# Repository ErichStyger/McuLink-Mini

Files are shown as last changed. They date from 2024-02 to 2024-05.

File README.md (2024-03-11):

# McuLink-Mini
Version of the NXP MCU-Link CMSIS-DAP Debug Probe with KiCad.
Many thanks to *Dario Scheuber* and his work to make this project possible!

## Background
This is the work of Dario Scheuber who created this debug probe as student at the Lucerne University of Applied Sciences and Arts at [IET](https://www.hslu.ch/en/lucerne-school-of-engineering-architecture/about-us/organization/institute/engineering-and-technology/elektrotechnik/). The project was done under the guidance of Prof. Erich Styger.

See blog article on https://mcuoneclipse.com/2024/02/06/versatile-oshw-mini-mcu-link-debug-probe-external-on-board-or-embedded/ for additional details.

## Features
This is an open hardware version of the NXP MCU-Link CMSIS-DAP debug probe, with following features and differences to the original MCU-Link:
- Open hardware design with KiCad
- Firmware compatibility with MCU-Link (LinkServer, CMSIS-DAP, ARM DAPLink)
- Dual-Layer design for lower costs
- USB-C connector instead of  Micro-USB
- USB-C connector usable to debug the LPC55S69
- 30% smaller than the original MCU-Link
- Firmware/boot push button instead of jumper
- Micro connector for UART connection instead of pin header
- Supports only 3.3V targets (no level shifters)
- Standalone version as external debug probe
- On-Board version: Solder external debug probe on your custom board (castellated pins)
- Embedded version: copy-paste into your custom board KiCad design
- BOM with assembly costs: ~$12/piece for 100 units

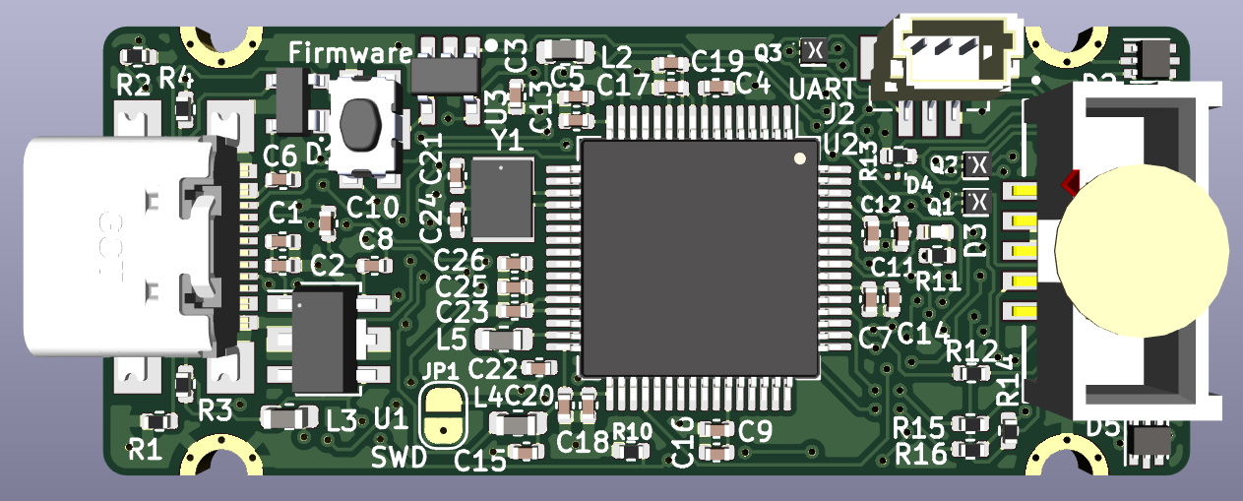
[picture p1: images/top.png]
top PCB

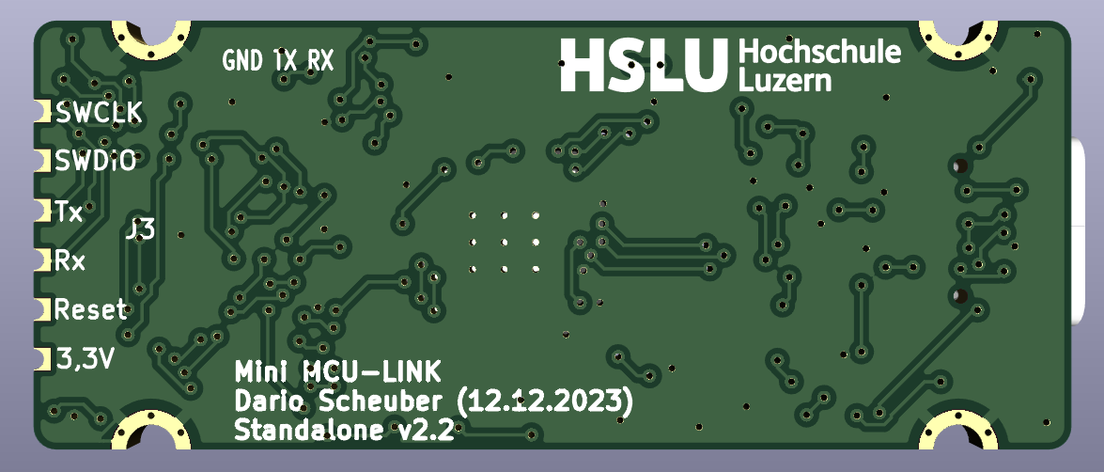
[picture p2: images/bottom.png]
bottom PCB


## Folders
- enclosure: 3D printed enclosure
- hardware: KiCad and hardware related files

## Links
- Article: https://mcuoneclipse.com/2024/02/06/versatile-oshw-mini-mcu-link-debug-probe-external-on-board-or-embedded/
- NXP MCU-Link: https://www.nxp.com/design/design-center/software/development-software/mcuxpresso-software-and-tools-/mcu-link-debug-probe:MCU-LINK
- KiCad: https://www.kicad.org/

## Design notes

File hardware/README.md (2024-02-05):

# Outline
This folder contains hardware releated files and folders:
- Gerber: production files
- KiCad: KiCad project files for the standalone, intergrated and component version of the PCB

# Errata Rev v2.1
following resistors need to be removed
- R7, R6, R9 (100 Ohm resistor for UART Rx, Tx and SWCLK)

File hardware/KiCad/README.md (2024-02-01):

Different versions of the debug probe:
- Standalone: used as standalone external debug probe
- Integrated: schematic and layout which can be pasted in your custom design
- Component: to place the standalone version with the castellated pins as component on your board

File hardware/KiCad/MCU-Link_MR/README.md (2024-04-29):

# MCU-Link

Project for the NXP MCU-Link Debug Probe with KiCAD, as a debug drone for mobile robotics platforms.

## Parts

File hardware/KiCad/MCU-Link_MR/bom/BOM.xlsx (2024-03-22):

Mouser | Vendor | Description | 1 | 10
200-SHF10501LDSM | SHF-105-01-L-D-SM | Sockel & Kabelgehäuse Shrouded Terminal Strip, 0.050" pitch | 2.88 | 2.62
771-LPC55S69JBD64K | LPC55S69JBD64K | LPC55S69JBD64 | 8.13 | 5.6
771-74LVC1T45GWQ100H | 74LVC1T45GW-Q100H | voltage converter 74LVC1T45GW-Q100/SOT363/SC-88 | 0.398 | 0.335
771-74LVC2T45DC125 | 74LVC2T45DC,125 | dual voltage converter/Bus transceiver | 0.658 | 0.546

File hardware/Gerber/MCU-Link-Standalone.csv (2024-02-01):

ID | Label | Footprint | Number | Description, Value | Reference
1 | JP1 | SolderJumper-2_P1.3mm_Open_RoundedPad1.0x1.5mm | 1 | SWD disable
2 | C22,C15,C26 | C_0402_1005Metric | 3 | 22u
3 | C21,C24 | C_0402_1005Metric | 2 | 8p
4 | J2 | JST_BM03B-SRSS-TB_LF__SN_ | 1 | BM03B-SRSS-TB
5 | U2 | LQFP-64-1EP_10x10mm_P0.5mm_EP5x5mm | 1 | LPC55S69JBD64
6 | L5 | L_0603_1608Metric | 1 | 4u7
7 | C8,C7,C25,C9,C5,C2,C18,C4,C11,C17 | C_0402_1005Metric | 10 | 100n
8 | D5,D2 | SOT-666 | 2 | PESD5V0L5UV
9 | Q2,Q3,Q1 | SOT1216 | 3 | PMDXB290UNE
10 | C10,C1 | C_0402_1005Metric | 2 | 10u
11 | R12,R6,R8,R5,R7,R9 | R_0402_1005Metric | 6 | 100
12 | C23,C19,C20 | C_0402_1005Metric | 3 | 47p
13 | SW1 | SW_C_K_KMR2 | 1 | KMR221GLFS
14 | D1 | SOT143B | 1 | PRTR5V0U2X
15 | R1,R2 | R_0402_1005Metric | 2 | 5k1
16 | U1 | SOT-89-5 | 1 | XC6227C331PR-G
17 | D3 | LED_0402_1005Metric | 1 | LED_RED
18 | C13,C6,C14,C12,C16 | C_0402_1005Metric | 5 | 10n
19 | L3,L4,L2 | L_0603_1608Metric | 3 | MI0603J601R-10
20 | R13,R14 | R_0402_1005Metric | 2 | 100k
21 | R11,R15 | R_0402_1005Metric | 2 | 2k
22 | R4 | R_0402_1005Metric | 1 | 20k
23 | U3 | SOT95P280X145-5N | 1 | STMPS2141STR
24 | D4 | Nexperia_DSN0603-2_0.6x0.3mm_P0.4mm | 1 | PMEG3005AESFYL
25 | J1 | USB_C_Receptacle_GCT_USB4110-GF-A | 1 | USB4110-GF-A_REVB
26 | R10,R3 | R_0402_1005Metric | 2 | 10k
27 | Y1 | CX3225GA16000D0PTVCC | 1 | 16.000MHz
28 | C3 | C_0402_1005Metric | 1 | 4u7
29 | R16 | R_0402_1005Metric | 1 | 10
30 | J3 | SWD_Pin_Header_Straight_2x05_Pitch1.27mm_SMD | 1 | Conn_02x05_Odd_Even

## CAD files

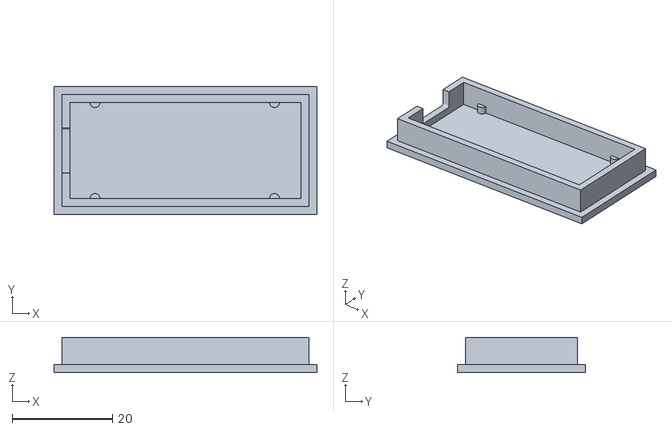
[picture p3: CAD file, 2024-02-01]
enclosure/stl/bottom.stl
52.6 x 25.6 x 7.00

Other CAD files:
enclosure/stl/top.stl
enclosure/Fusion360/bottom.f3d
enclosure/Fusion360/mini MCU-LINK assembly.f3z
enclosure/Fusion360/top.f3d

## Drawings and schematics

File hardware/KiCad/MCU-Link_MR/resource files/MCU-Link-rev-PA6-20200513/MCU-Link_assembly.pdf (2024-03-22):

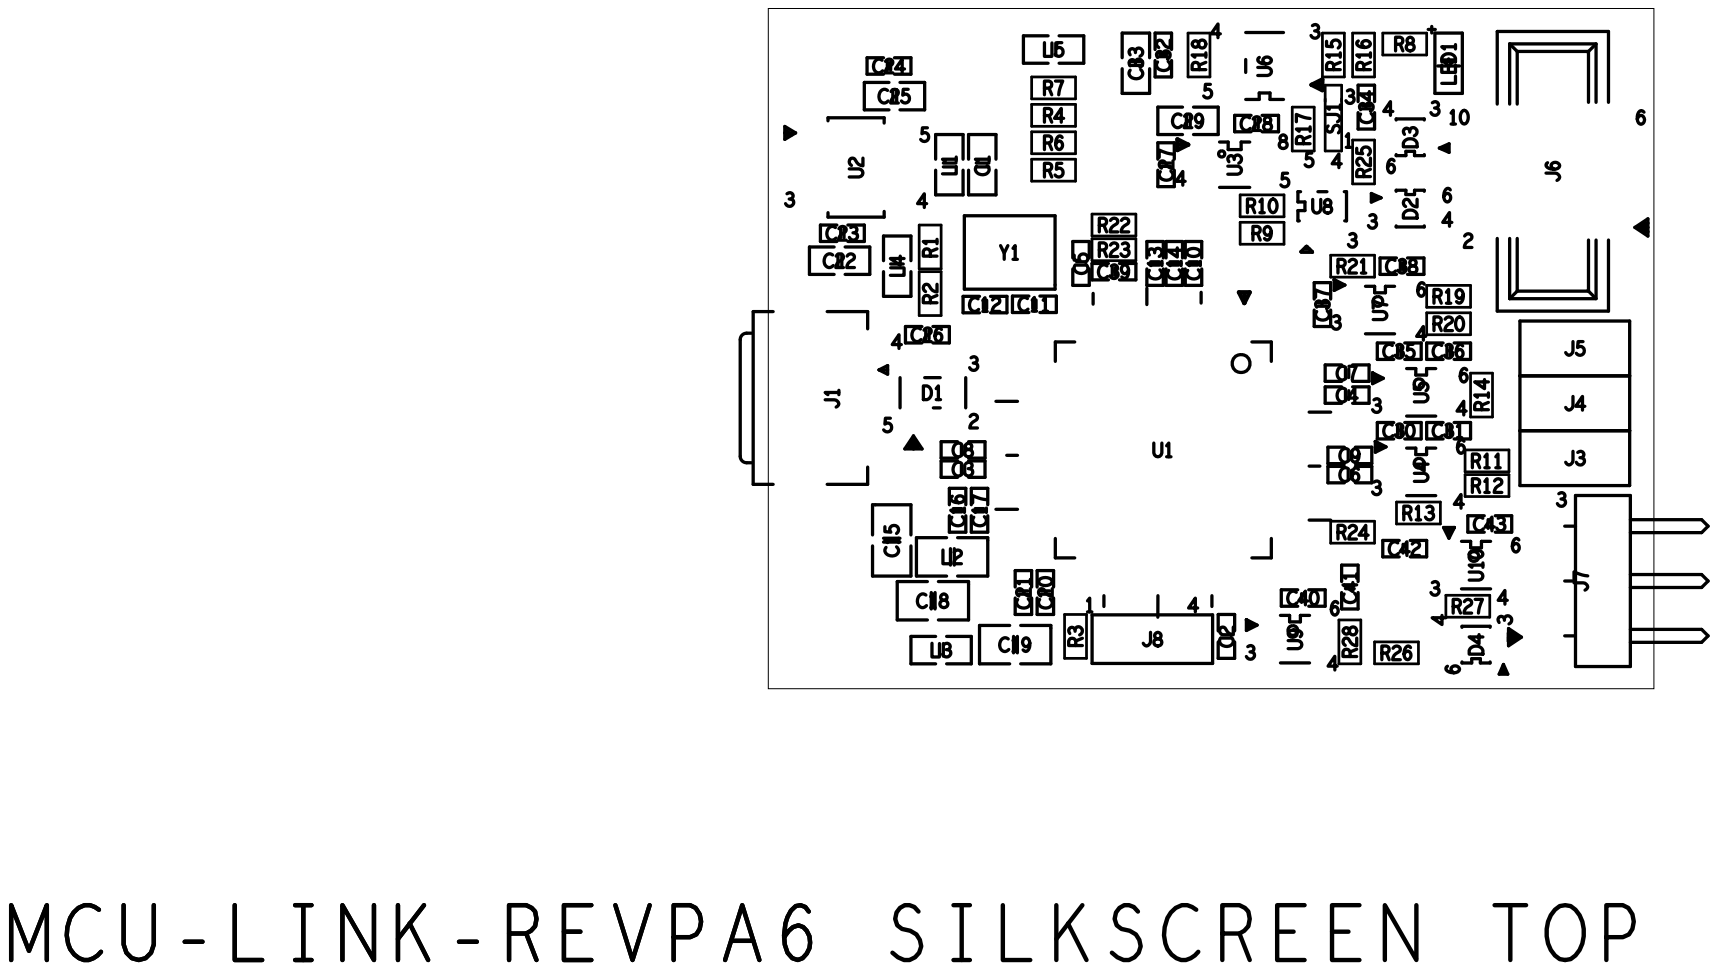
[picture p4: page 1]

MCU-LINK-REVPA6 SILKSCREEN TOP MCU-LINK-REVPA6

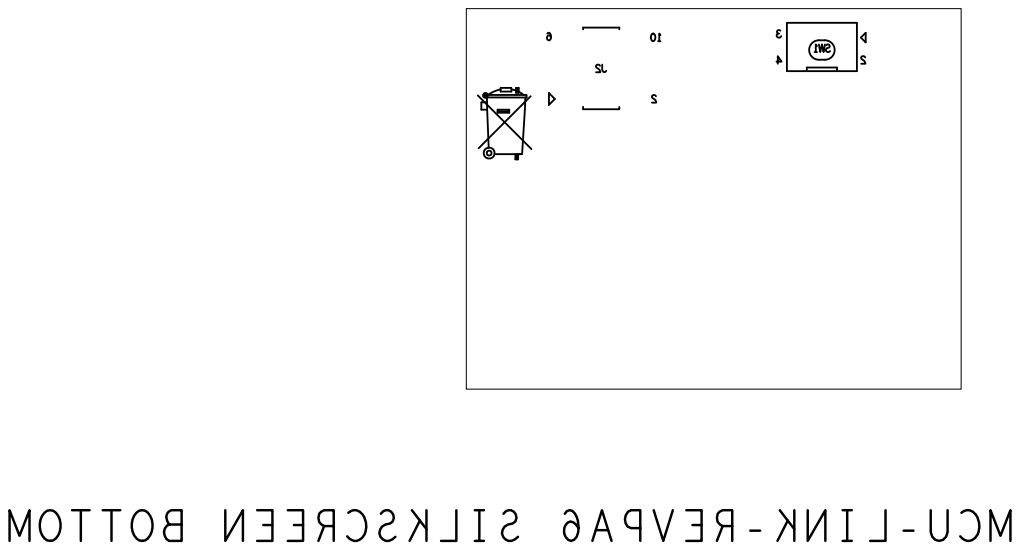
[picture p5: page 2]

MCU-LINK-REVPA6 SILKSCREEN BOTTOM

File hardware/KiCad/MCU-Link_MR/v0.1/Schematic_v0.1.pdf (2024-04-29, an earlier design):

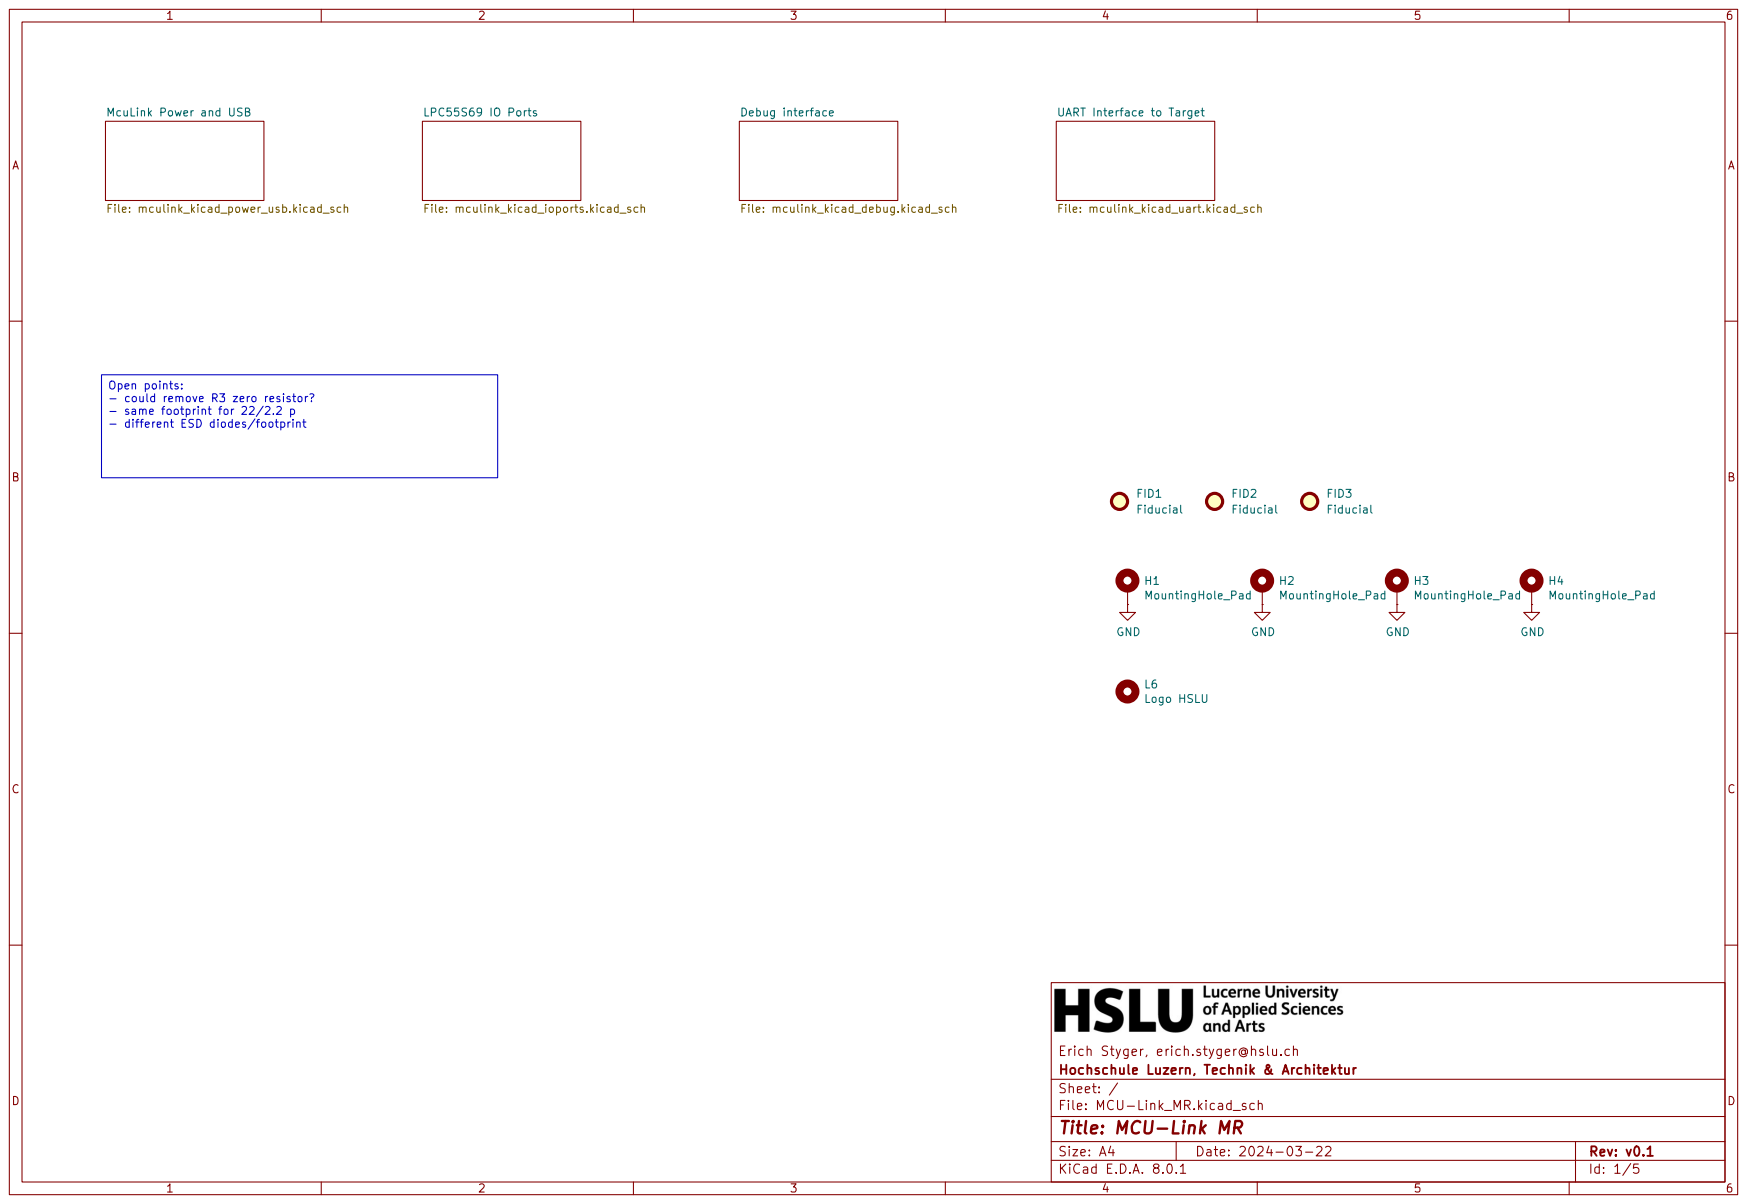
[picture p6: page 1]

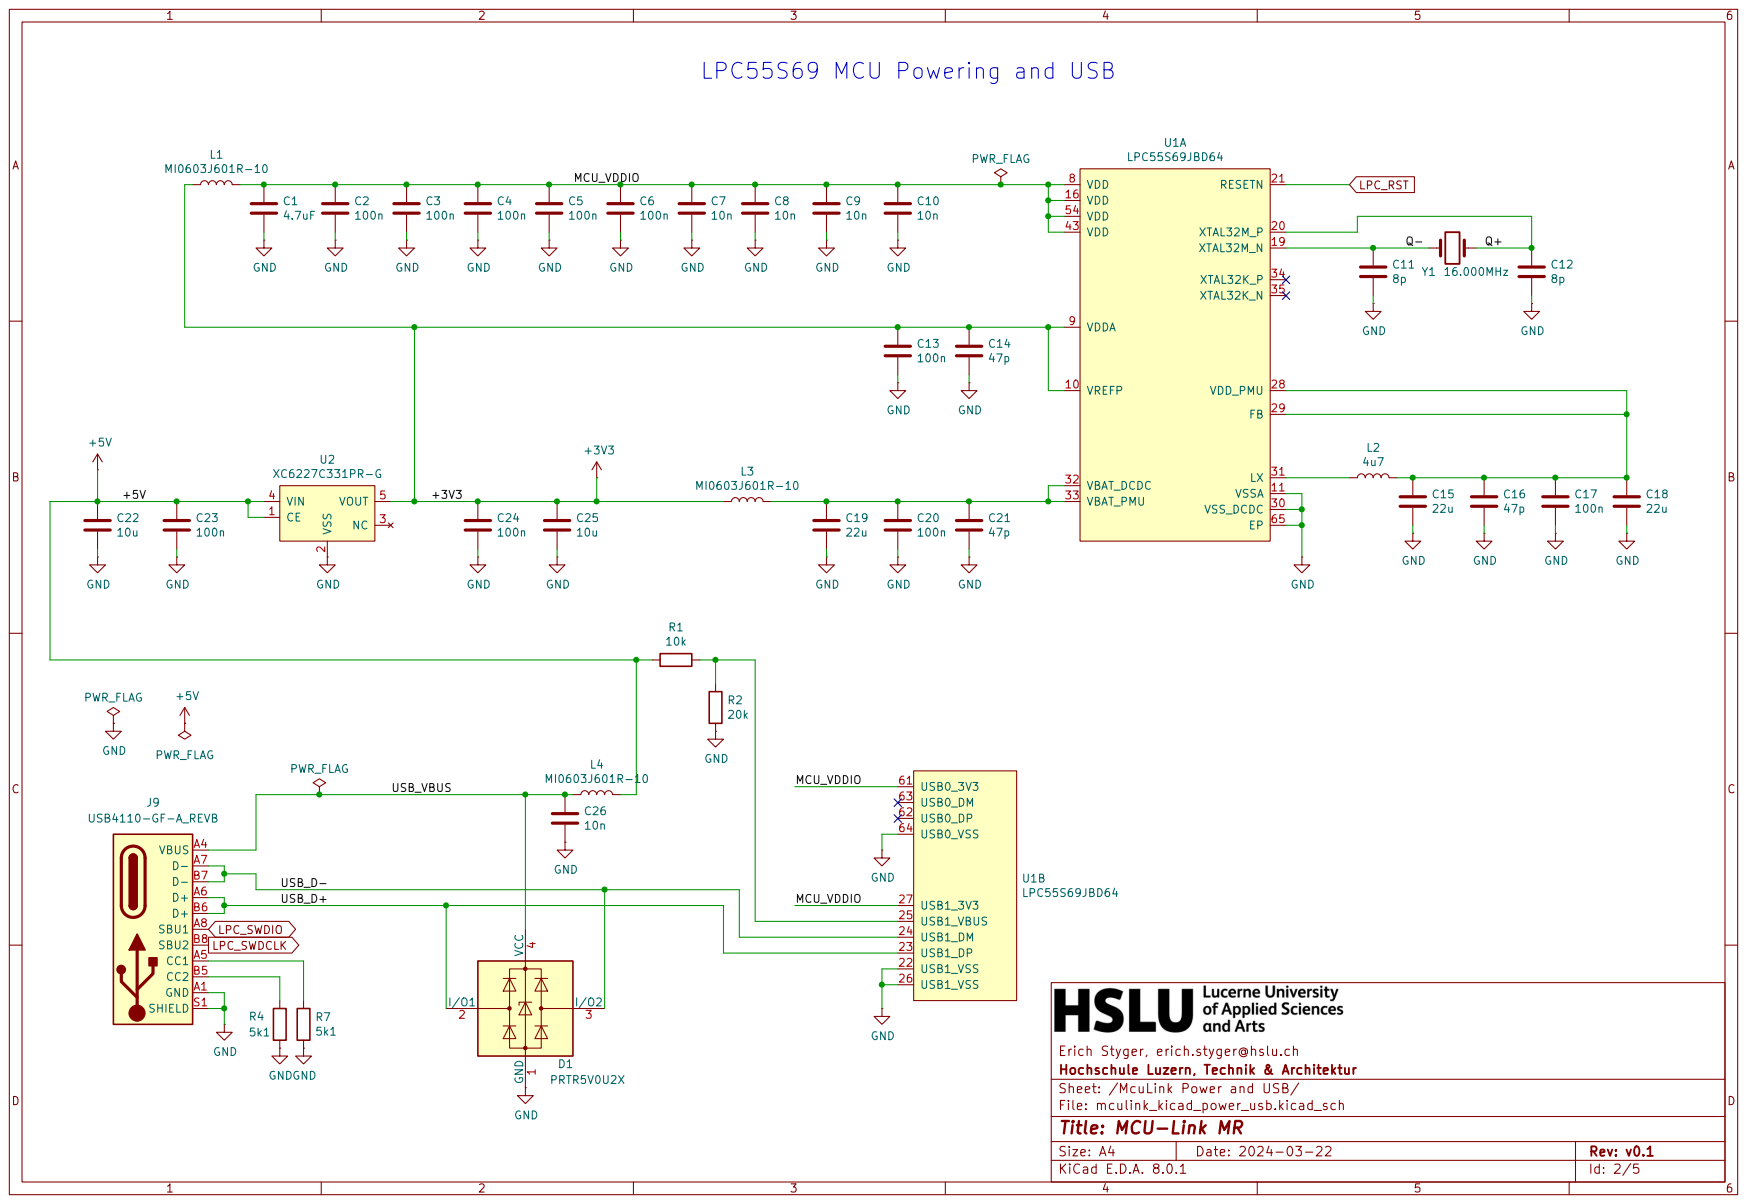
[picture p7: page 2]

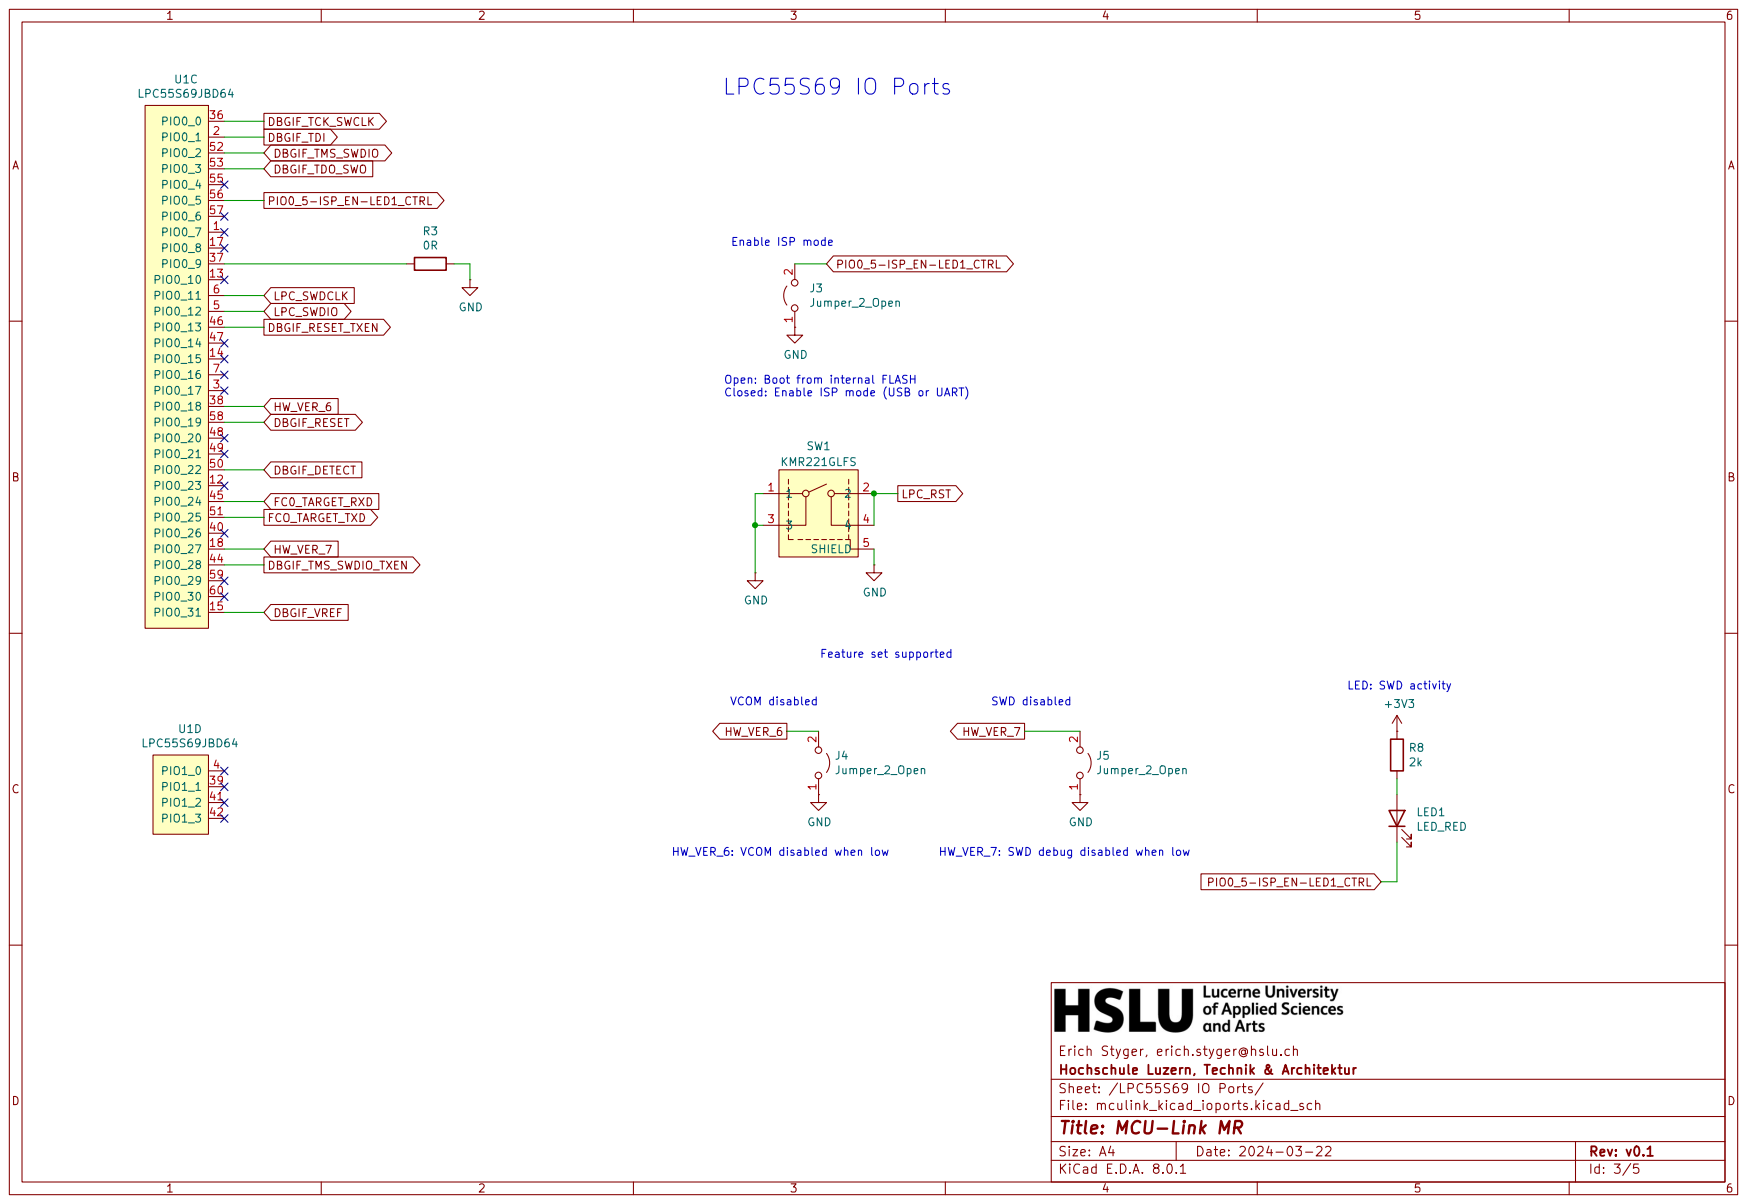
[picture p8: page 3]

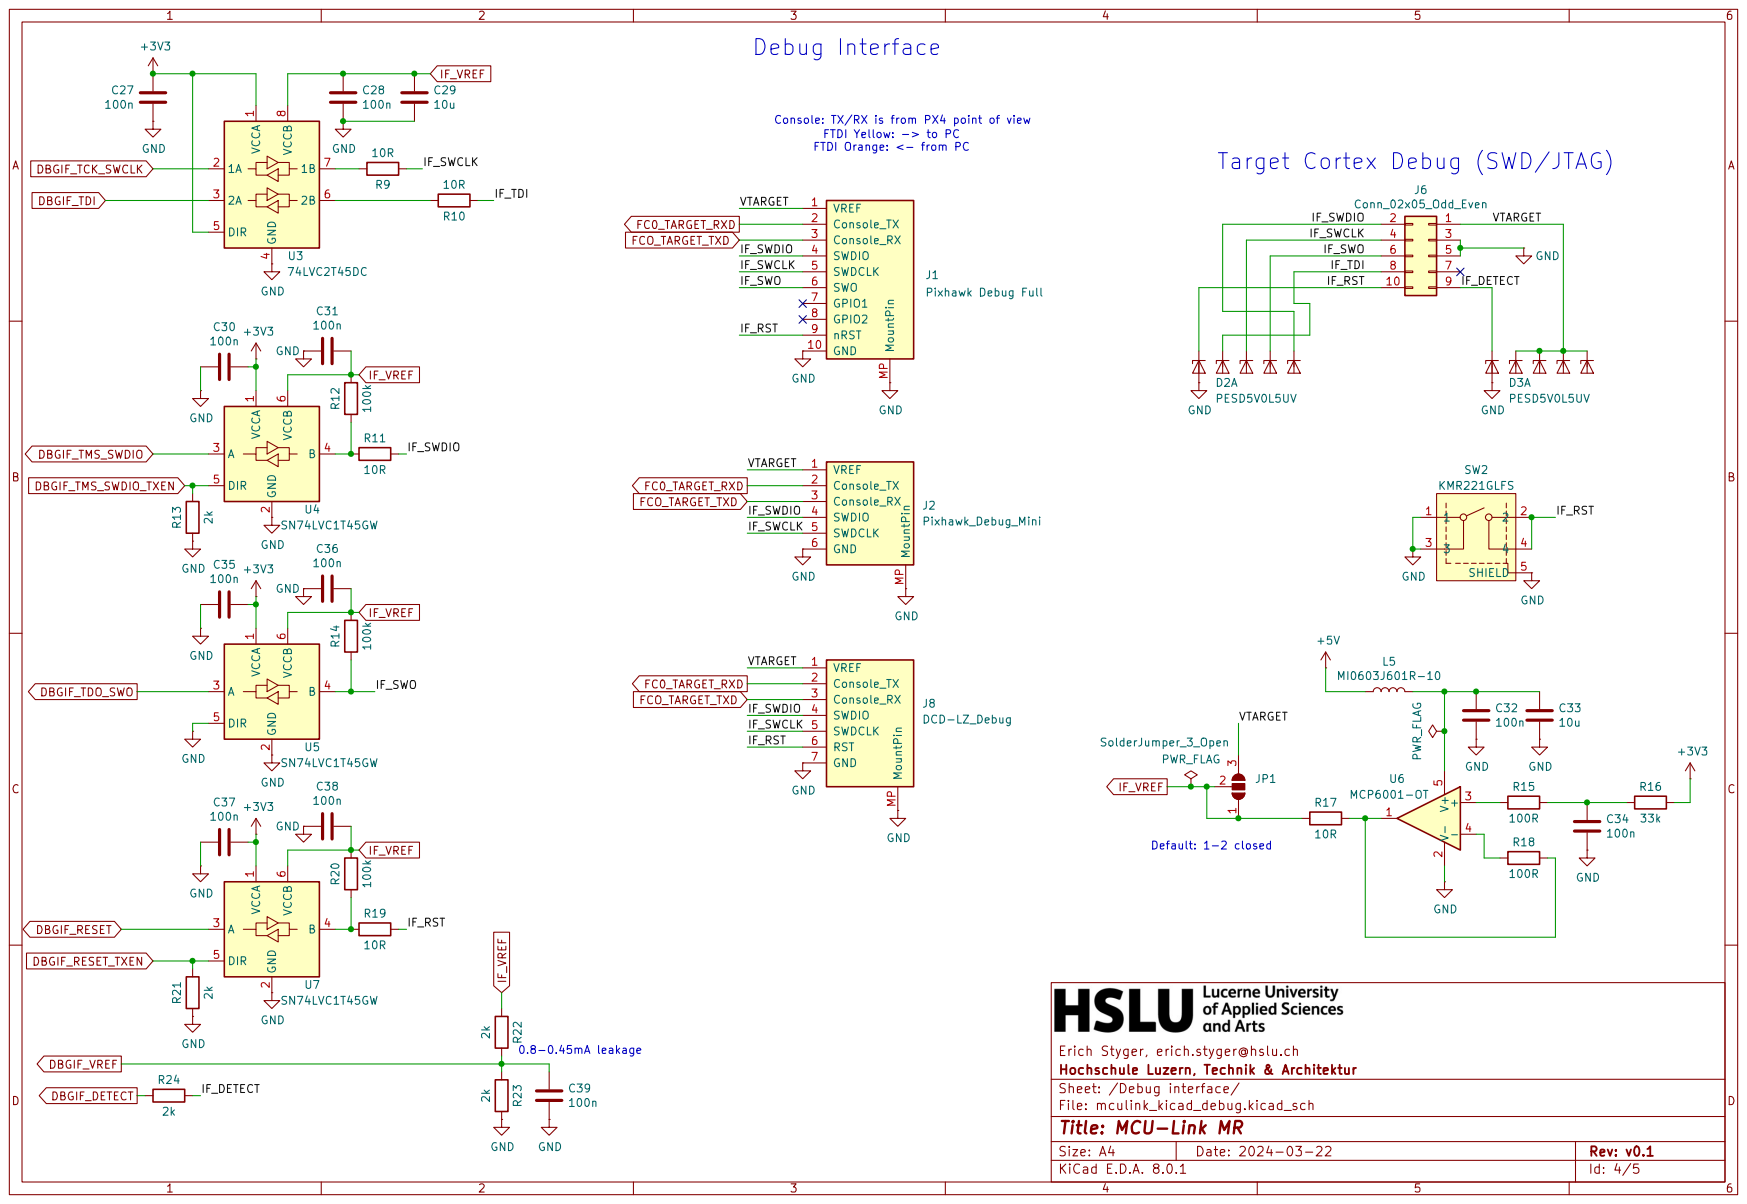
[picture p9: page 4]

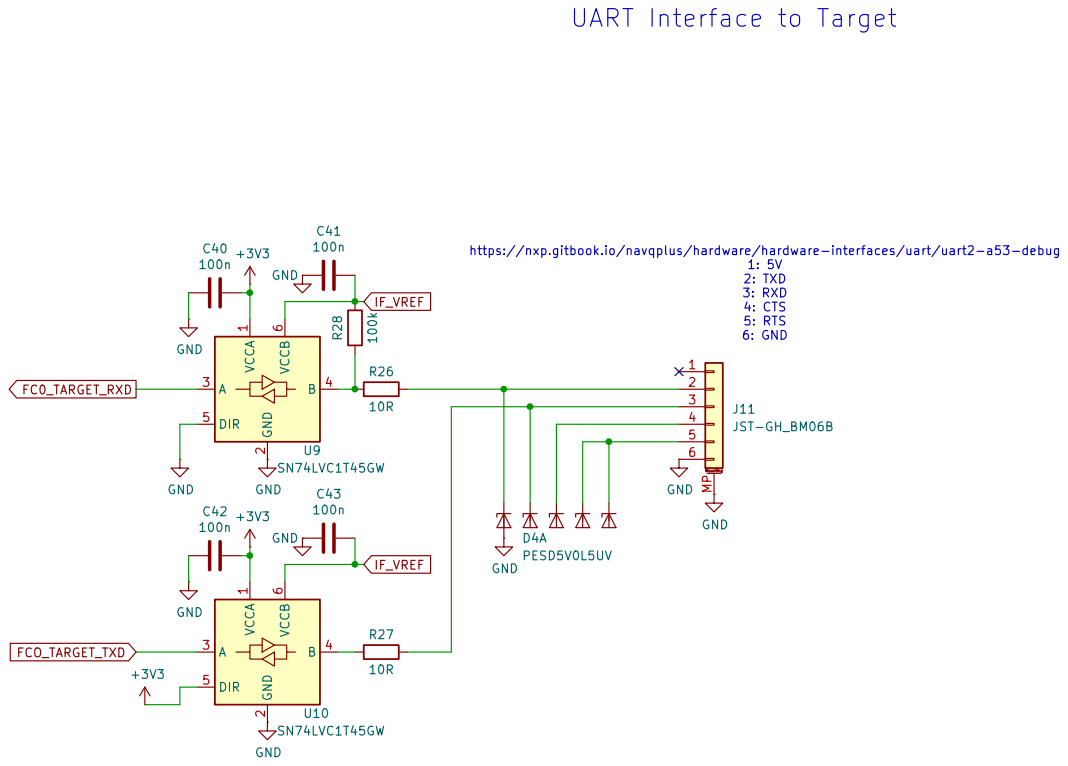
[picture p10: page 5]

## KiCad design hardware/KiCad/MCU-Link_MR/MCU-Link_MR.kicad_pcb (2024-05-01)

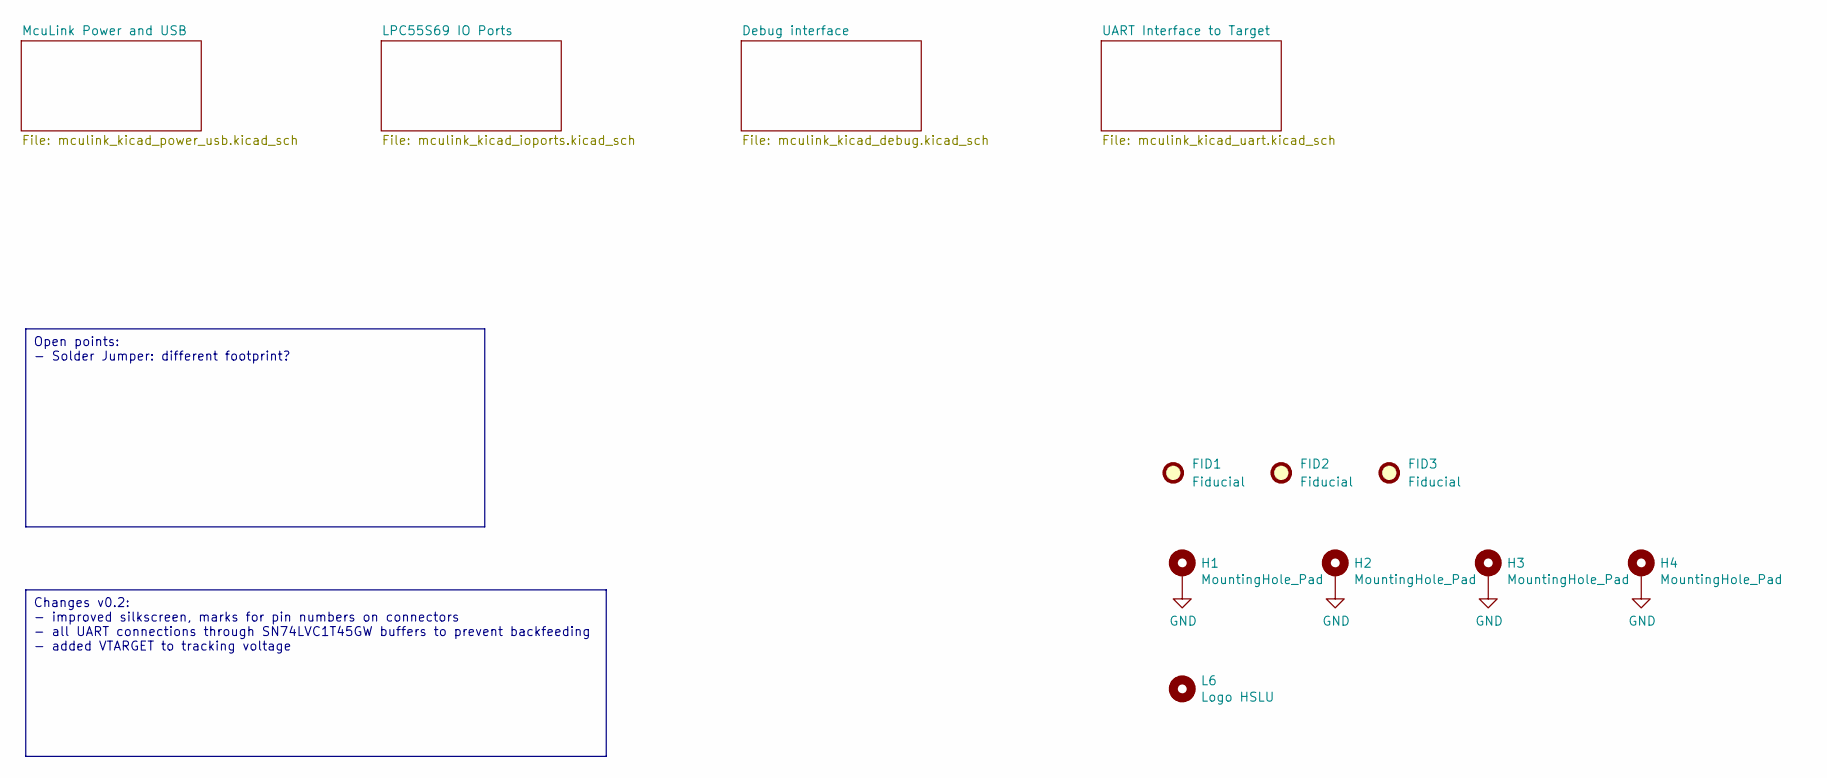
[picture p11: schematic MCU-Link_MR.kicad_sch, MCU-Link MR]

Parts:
FID1, FID2, FID3: Fiducial; Fiducial_1mm_Dia_2.54mm_Outer_CopperTop
H1, H2, H3, H4: MountingHole_Pad; MountingHole_2.7mm_M2.5_DIN965_Pad
L6: Logo HSLU; Hochschule_Luzern_New

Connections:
GND: H1.1, H2.1, H3.1, H4.1; also elsewhere on the board

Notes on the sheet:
Open points: - Solder Jumper: different footprint?
Changes v0.2: - improved silkscreen, marks for pin numbers on connectors - all UART connections through SN74LVC1T45GW buffers to prevent backfeeding - added VTARGET to tracking voltage

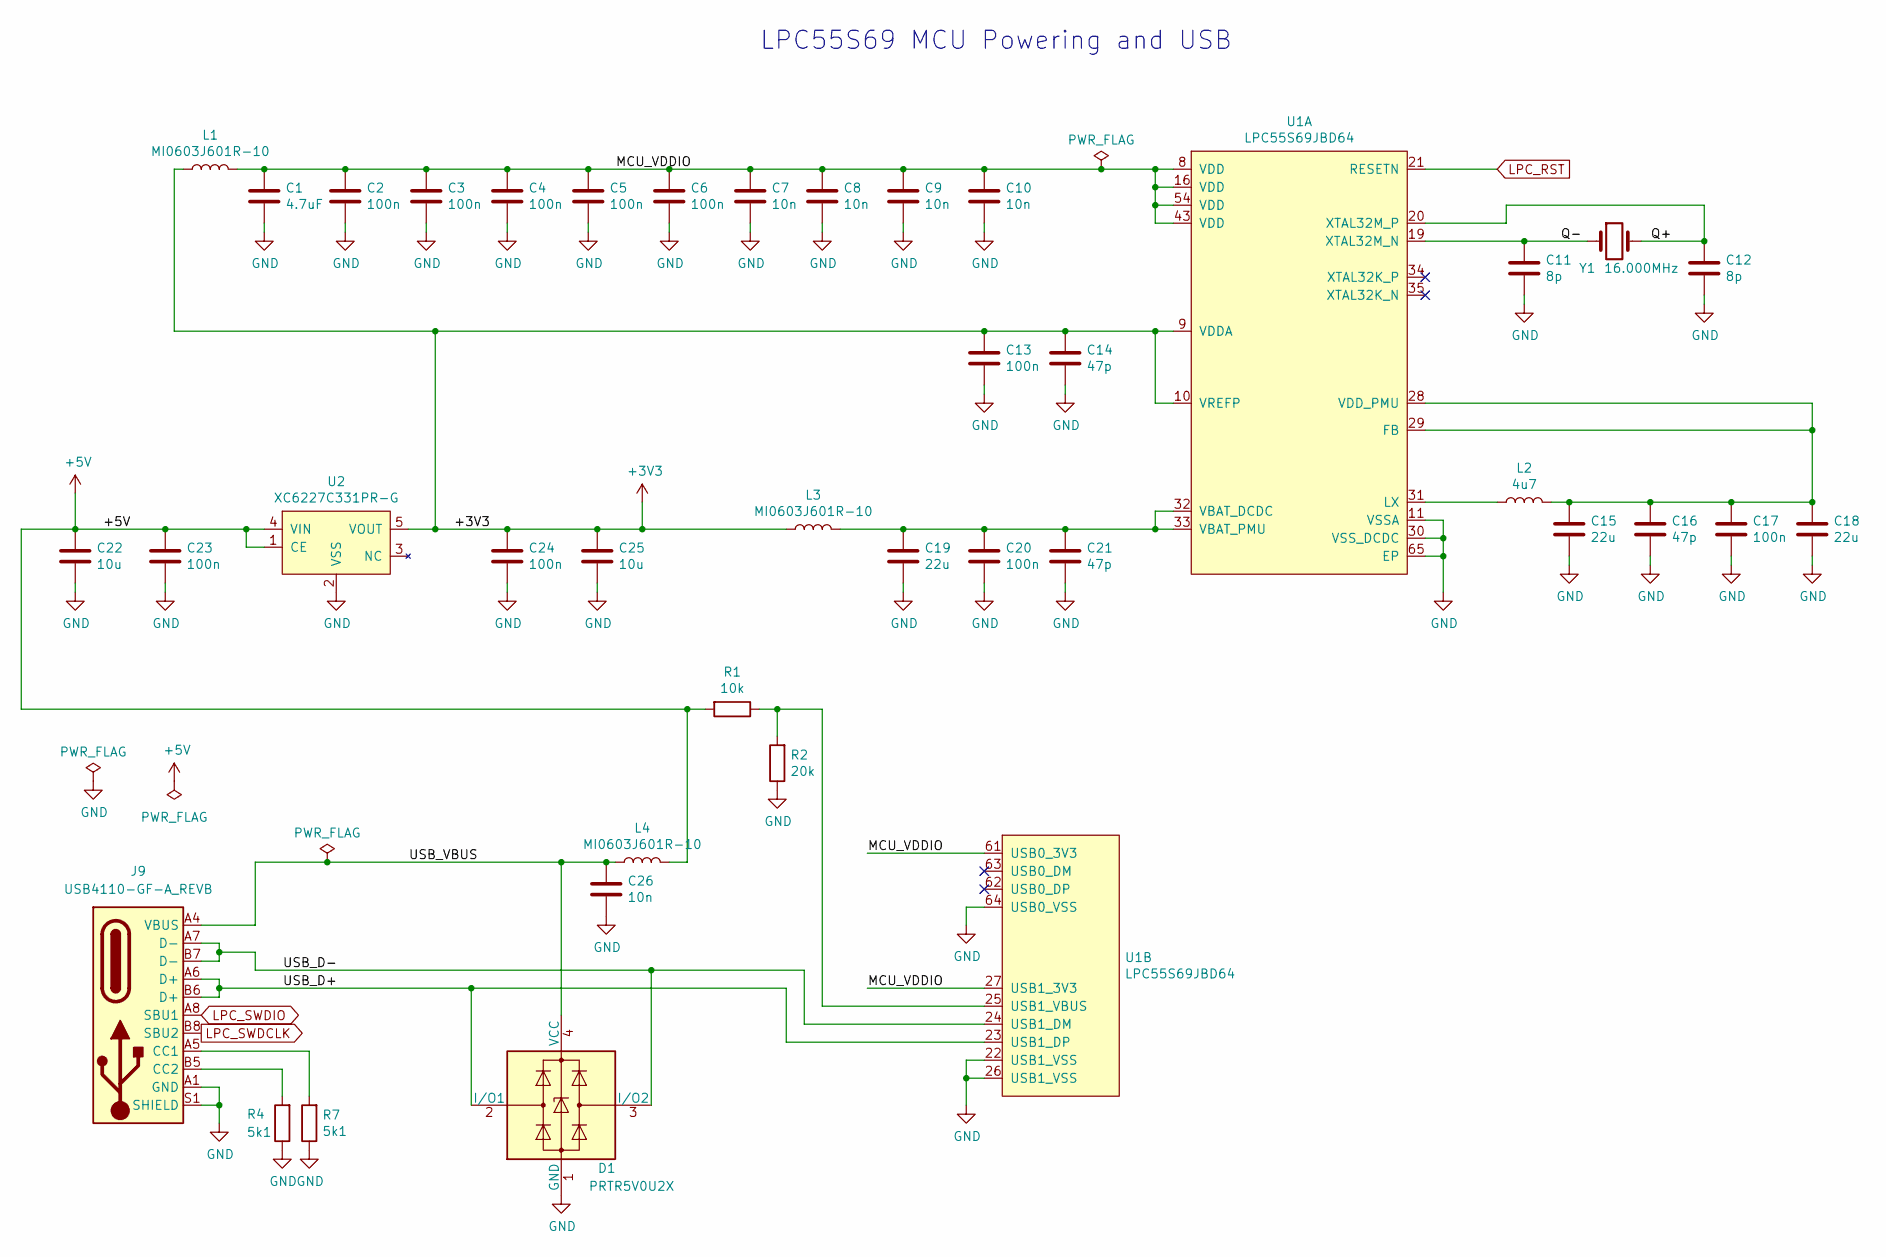
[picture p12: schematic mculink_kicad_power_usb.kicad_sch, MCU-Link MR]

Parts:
C1: 4.7uF; C_0603_1608Metric
C2, C3, C4, C5, C6, C13, C17, C20, C23, C24: 100n; C_0603_1608Metric
C7, C8, C9, C10, C26: 10n; C_0603_1608Metric
C11, C12: 8p; C_0603_1608Metric
C14, C16, C21: 47p; C_0603_1608Metric
C15, C19: 22u; C_0805_2012Metric
C18: 22u; C_0603_1608Metric
C22, C25: 10u; C_0603_1608Metric
D1: PRTR5V0U2X; SOT-143
J9: USB4110-GF-A_REVB; USB_C_Receptacle_GCT_USB4110-GF-A; PARTREV B; mouser# 640-USB4110-GF-A
L1, L3, L4: MI0603J601R-10; L_0603_1608Metric
L2: 4u7; L_0805_2012Metric
R1: 10k; R_0603_1608Metric
R2: 20k; R_0603_1608Metric
R4, R7: 5k1; R_0603_1608Metric
U1: LPC55S69JBD64; LQFP-64-1EP_10x10mm_P0.5mm_EP3.5x3.5mm
U2: XC6227C331PR-G; SOT-89-5
Y1: 16.000MHz; CX3225GA16000D0PTVCC

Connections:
+3V3: C13.1, C14.1, C24.1, C25.1, L1.1, L3.1, U1.9 (VDDA), U1.10 (VREFP), U2.5 (VOUT); also elsewhere on the board
+5V: C22.1, C23.1, L4.2, R1.2, U2.1 (CE), U2.4 (VIN); also elsewhere on the board
/McuLink Power and USB/MCU_VDDIO: C1.1, C2.1, C3.1, C4.1, C5.1, C6.1, C7.1, C8.1, C9.1, C10.1, L1.2, U1.8 (VDD), U1.16 (VDD), U1.27 (USB1_3V3), U1.43 (VDD), U1.54 (VDD), U1.61 (USB0_3V3)
/McuLink Power and USB/Q+: C12.1, U1.20 (XTAL32M_P), Y1.2
/McuLink Power and USB/Q-: C11.1, U1.19 (XTAL32M_N), Y1.1
/McuLink Power and USB/USB_D+: D1.2 (I/O1), J9.A6 (D+), J9.B6 (D+), U1.23 (USB1_DP)
/McuLink Power and USB/USB_D-: D1.3 (I/O2), J9.A7 (D-), J9.B7 (D-), U1.24 (USB1_DM)
/McuLink Power and USB/USB_VBUS: C26.1, D1.4 (VCC), J9.A4 (VBUS), J9.A9 (VBUS), J9.B4 (VBUS), J9.B9 (VBUS), L4.1
GND: C1.2, C2.2, C3.2, C4.2, C5.2, C6.2, C7.2, C8.2, C9.2, C10.2, C11.2, C12.2, C13.2, C14.2, C15.2, C16.2, C17.2, C18.2, C19.2, C20.2, C21.2, C22.2, C23.2, C24.2, C25.2, C26.2, D1.1 (GND), J9.A1 (GND), J9.A12 (GND), J9.B1 (GND), J9.B12 (GND), J9.S1 (SHIELD), R2.1, R4.1, R7.1, U1.11 (VSSA), U1.22 (USB1_VSS), U1.26 (USB1_VSS), U1.30 (VSS_DCDC), U1.64 (USB0_VSS), U1.65 (EP), U2.2 (VSS); also elsewhere on the board
LPC_RST: U1.21 (RESETN); also elsewhere on the board
LPC_SWDCLK: J9.B8 (SBU2); also elsewhere on the board
LPC_SWDIO: J9.A8 (SBU1); also elsewhere on the board
unnamed: J9.A5 (CC1), R7.2
unnamed: J9.B5 (CC2), R4.2
unnamed: C15.1, C16.1, C17.1, C18.1, L2.2, U1.28 (VDD_PMU), U1.29 (FB)
unnamed: L2.1, U1.31 (LX)
unnamed: C19.1, C20.1, C21.1, L3.2, U1.32 (VBAT_DCDC), U1.33 (VBAT_PMU)
unnamed: R1.1, R2.2, U1.25 (USB1_VBUS)

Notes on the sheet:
LPC55S69 MCU Powering and USB

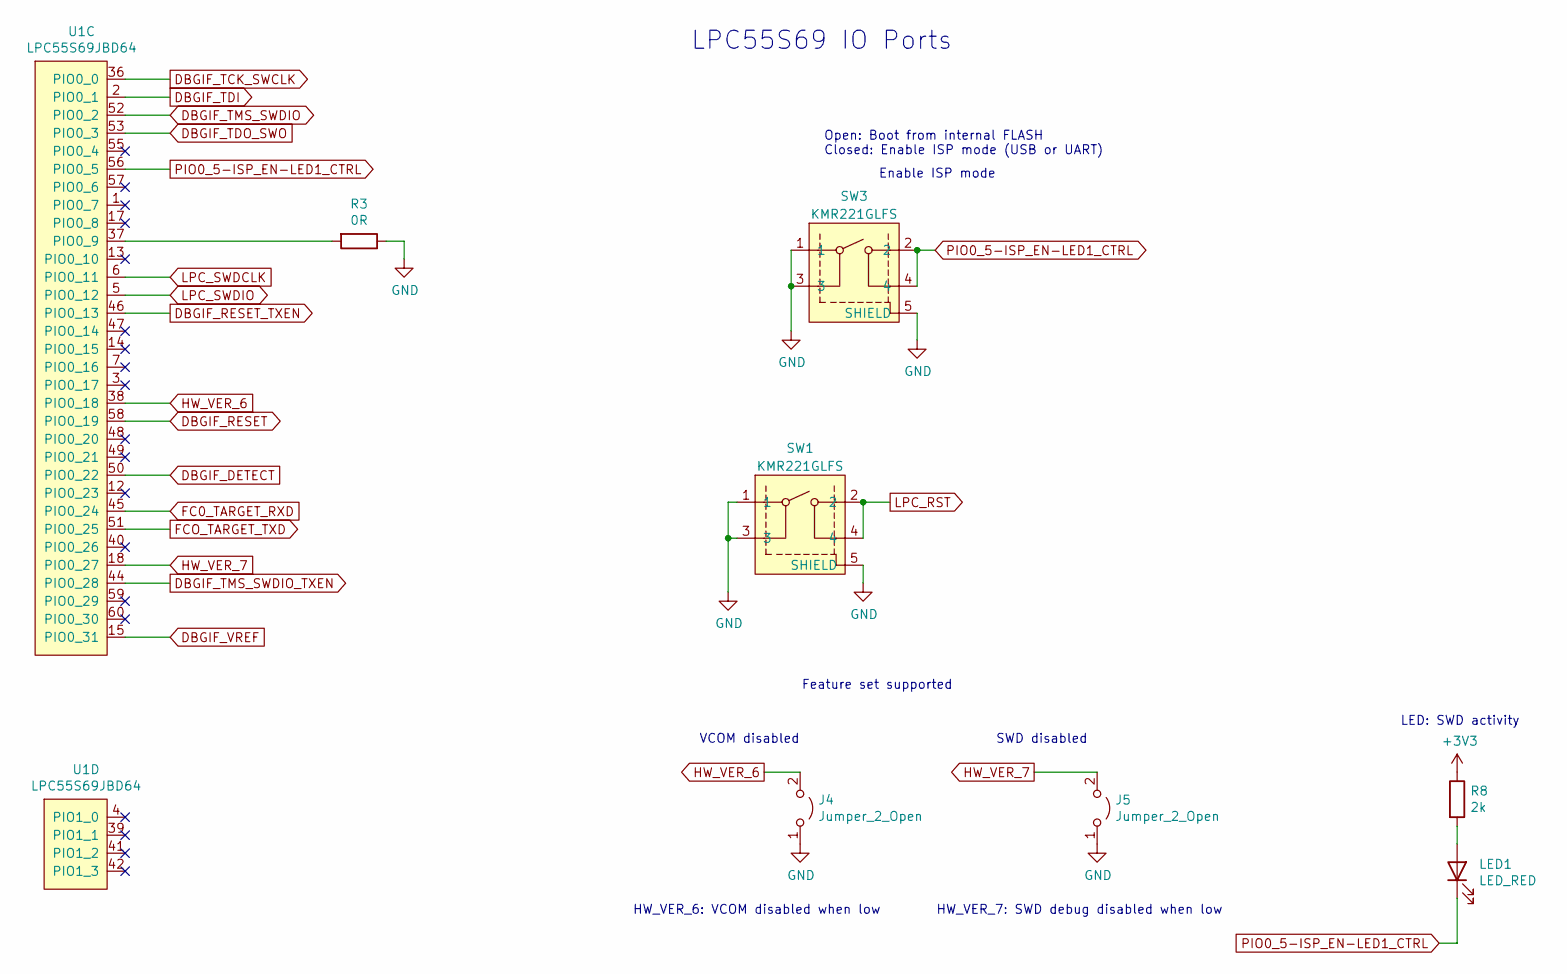
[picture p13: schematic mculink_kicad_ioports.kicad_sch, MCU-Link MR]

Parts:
J4, J5: Jumper_2_Open; SolderJumper-2_P1.3mm_Open_RoundedPad1.0x1.5mm
LED1: LED_RED; LED_0603_1608Metric
R3: 0R; R_0603_1608Metric
R8: 2k; R_0603_1608Metric
SW1, SW3: KMR221GLFS; SW_C_K_KMR2
U1: LPC55S69JBD64; LQFP-64-1EP_10x10mm_P0.5mm_EP3.5x3.5mm

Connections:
+3V3: R8.1; also elsewhere on the board
DBGIF_DETECT: U1.50 (PIO0_22); also elsewhere on the board
DBGIF_RESET: U1.58 (PIO0_19); also elsewhere on the board
DBGIF_RESET_TXEN: U1.46 (PIO0_13); also elsewhere on the board
DBGIF_TCK_SWCLK: U1.36 (PIO0_0); also elsewhere on the board
DBGIF_TDI: U1.2 (PIO0_1); also elsewhere on the board
DBGIF_TDO_SWO: U1.53 (PIO0_3); also elsewhere on the board
DBGIF_TMS_SWDIO: U1.52 (PIO0_2); also elsewhere on the board
DBGIF_TMS_SWDIO_TXEN: U1.44 (PIO0_28); also elsewhere on the board
DBGIF_VREF: U1.15 (PIO0_31); also elsewhere on the board
FC0_TARGET_RXD: U1.45 (PIO0_24); also elsewhere on the board
FCO_TARGET_TXD: U1.51 (PIO0_25); also elsewhere on the board
GND: J4.1 (A), J5.1 (A), R3.1, SW1.1, SW1.3, SW1.5 (SHIELD), SW3.1, SW3.3, SW3.5 (SHIELD); also elsewhere on the board
HW_VER_6: J4.2 (B), U1.38 (PIO0_18)
HW_VER_7: J5.2 (B), U1.18 (PIO0_27)
LPC_RST: SW1.2, SW1.4; also elsewhere on the board
LPC_SWDCLK: U1.6 (PIO0_11); also elsewhere on the board
LPC_SWDIO: U1.5 (PIO0_12); also elsewhere on the board
unnamed: LED1.2 (A), R8.2
unnamed: R3.2, U1.37 (PIO0_9)
PIO0_5-ISP_EN-LED1_CTRL: LED1.1 (K), SW3.2, SW3.4, U1.56 (PIO0_5)

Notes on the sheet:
Open: Boot from internal FLASH Closed: Enable ISP mode (USB or UART)
VCOM disabled
Enable ISP mode
HW_VER_7: SWD debug disabled when low
Feature set supported
SWD disabled
LPC55S69 IO Ports
HW_VER_6: VCOM disabled when low
LED: SWD activity

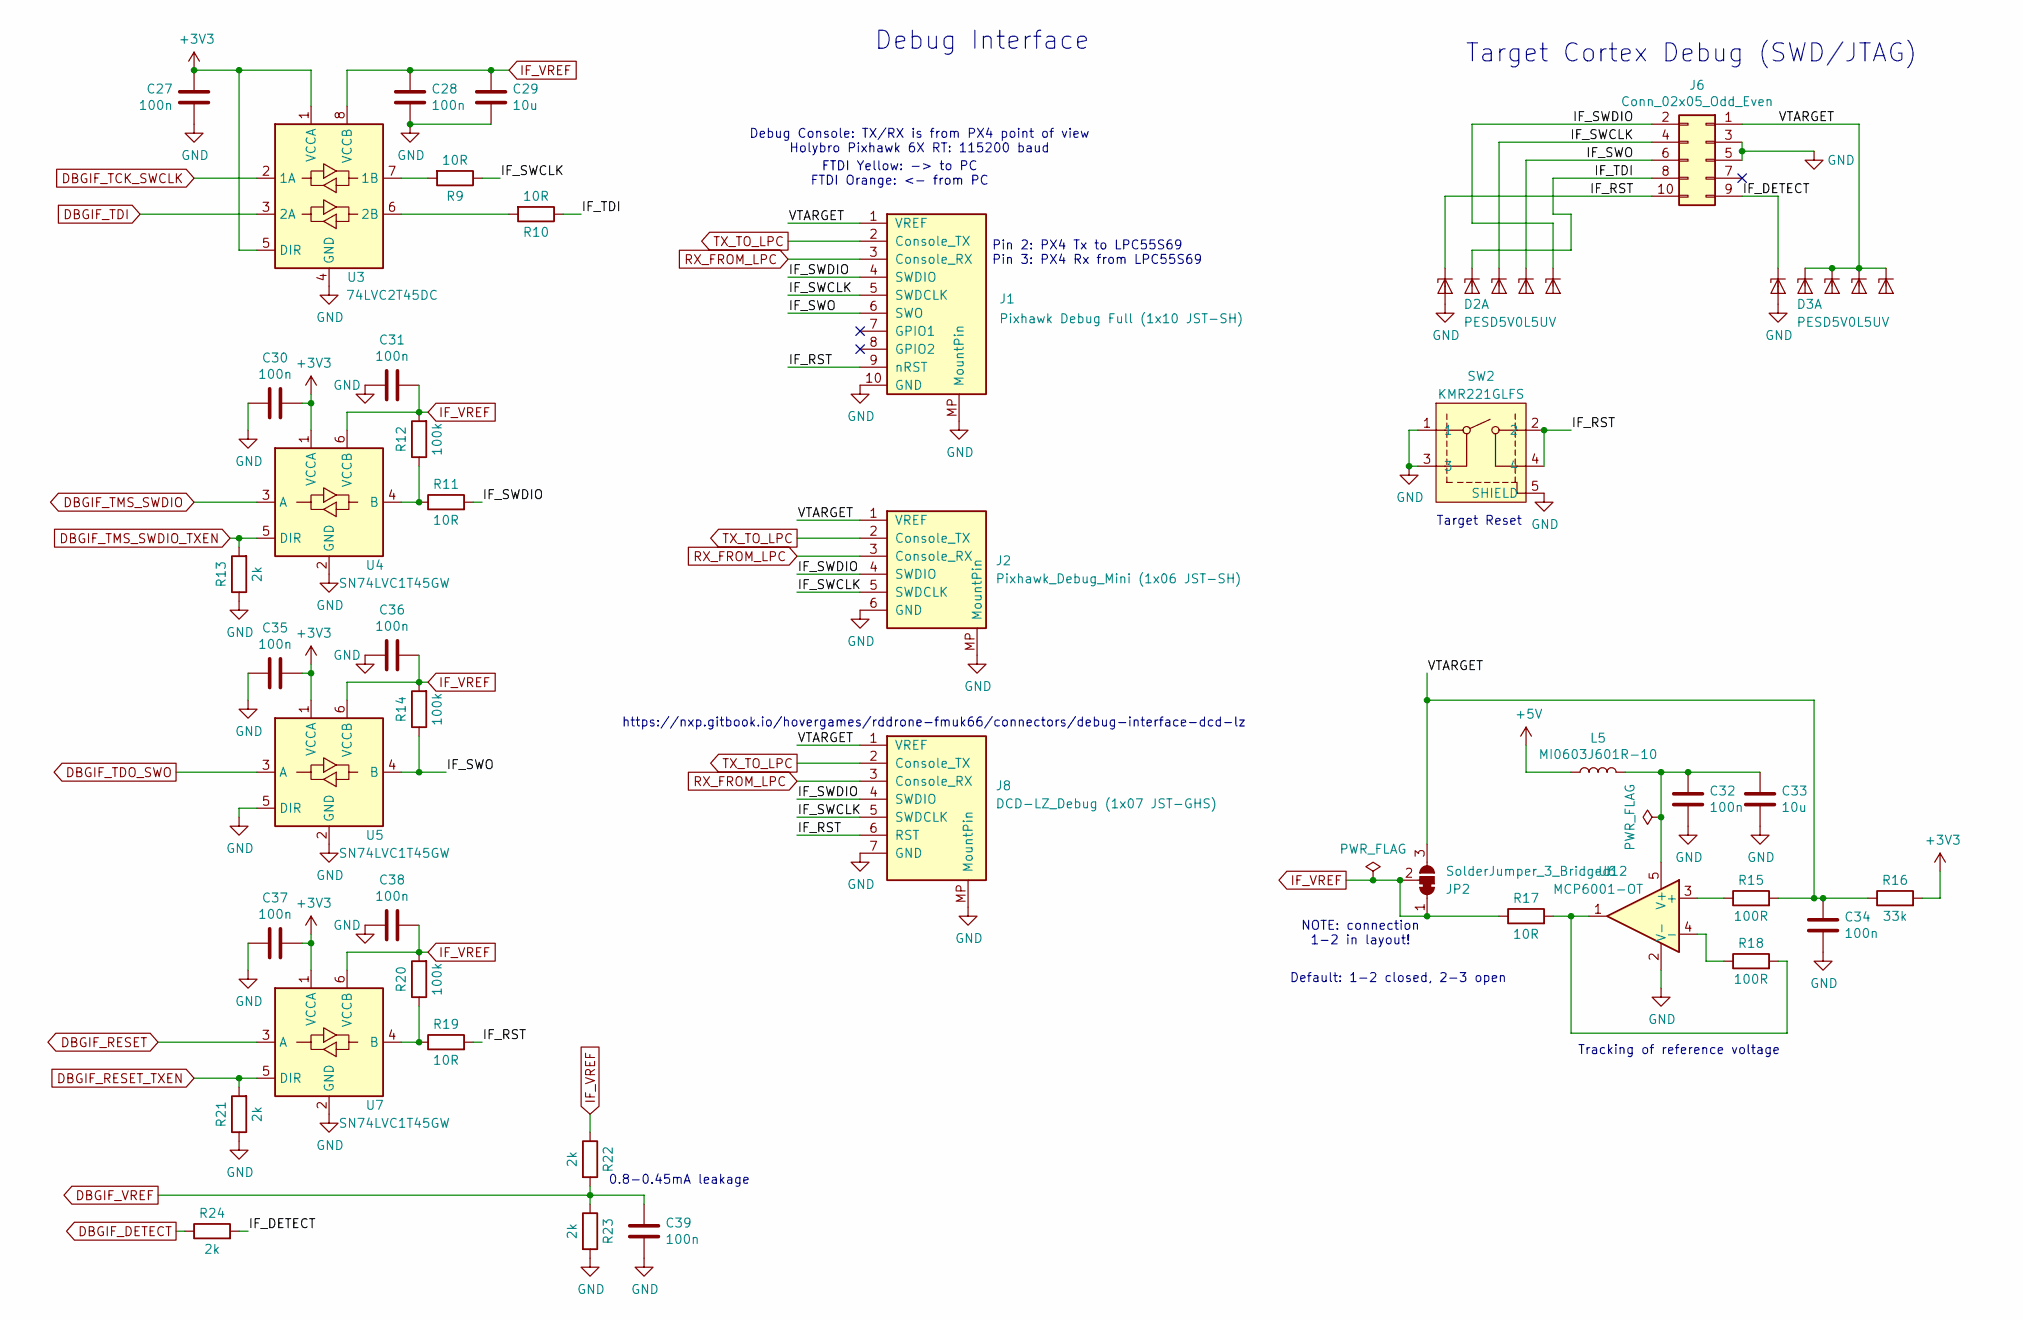
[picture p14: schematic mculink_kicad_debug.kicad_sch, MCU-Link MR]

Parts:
C27, C28, C30, C31, C32, C34, C35, C36, C37, C38, C39: 100n; C_0603_1608Metric
C29, C33: 10u; C_0603_1608Metric
D2, D3: PESD5V0L5UV; SOT-666
J1: Pixhawk Debug Full (1x10 JST-SH); JST_SH_SM10B-SRSS-TB_1x10-1MP_P1.00mm_Horizontal
J2: Pixhawk_Debug_Mini (1x06 JST-SH); JST_SH_BM06B-SRSS-TB_1x06-1MP_P1.00mm_Vertical
J6: Conn_02x05_Odd_Even; SWD_Pin_Header_Straight_2x05_Pitch1.27mm_SMD_Shrouded
J8: DCD-LZ_Debug (1x07 JST-GHS); JST_GH_SM07B-GHS-TB_1x07-1MP_P1.25mm_Horizontal
JP2: SolderJumper_3_Bridged12; SolderJumper-3_P1.3mm_Open_RoundedPad1.0x1.5mm
L5: MI0603J601R-10; L_0603_1608Metric
R9, R10, R11, R17, R19: 10R; R_0603_1608Metric
R12, R14, R20: 100k; R_0603_1608Metric
R13, R21, R22, R23, R24: 2k; R_0603_1608Metric
R15, R18: 100R; R_0603_1608Metric
R16: 33k; R_0603_1608Metric
SW2: KMR221GLFS; SW_C_K_KMR2
U3: 74LVC2T45DC; VSSOP-8_2.3x2mm_P0.5mm
U4, U5, U7: SN74LVC1T45GW; SOT-363_SC-70-6
U6: MCP6001-OT; SOT-23-5

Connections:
+3V3: C27.2, C30.2, C35.2, C37.2, R16.2, U3.1 (VCCA), U3.5 (DIR), U4.1 (VCCA), U5.1 (VCCA), U7.1 (VCCA); also elsewhere on the board
+5V: L5.1; also elsewhere on the board
/Debug interface/IF_DETECT: D3.1 (K1), J6.9, R24.2
/Debug interface/IF_RST: D2.1 (K1), J1.9 (nRST), J6.10, J8.6 (RST), R19.2, SW2.2, SW2.4
/Debug interface/IF_SWCLK: D2.4 (K3), J1.5 (SWDCLK), J2.5 (SWDCLK), J6.4, J8.5 (SWDCLK), R9.1
/Debug interface/IF_SWDIO: D2.6 (K5), J1.4 (SWDIO), J2.4 (SWDIO), J6.2, J8.4 (SWDIO), R11.2
/Debug interface/IF_SWO: D2.5 (K4), J1.6 (SWO), J6.6, R14.1, U5.4 (B)
/Debug interface/IF_TDI: D2.3 (K2), J6.8, R10.1
/Debug interface/VTARGET: C34.1, D3.3 (K2), D3.4 (K3), D3.5 (K4), D3.6 (K5), J1.1 (VREF), J2.1 (VREF), J6.1, J8.1 (VREF), JP2.3 (B), R15.2, R16.1
DBGIF_DETECT: R24.1; also elsewhere on the board
DBGIF_RESET: U7.3 (A); also elsewhere on the board
DBGIF_RESET_TXEN: R21.2, U7.5 (DIR); also elsewhere on the board
DBGIF_TCK_SWCLK: U3.2 (1A); also elsewhere on the board
DBGIF_TDI: U3.3 (2A); also elsewhere on the board
DBGIF_TDO_SWO: U5.3 (A); also elsewhere on the board
DBGIF_TMS_SWDIO: U4.3 (A); also elsewhere on the board
DBGIF_TMS_SWDIO_TXEN: R13.2, U4.5 (DIR); also elsewhere on the board
DBGIF_VREF: C39.1, R22.2, R23.1; also elsewhere on the board
GND: C27.1, C28.2, C29.2, C30.1, C31.1, C32.2, C33.2, C34.2, C35.1, C36.1, C37.1, C38.1, C39.2, D2.2 (A), D3.2 (A), J1.10 (GND), J1.MP (MountPin), J2.6 (GND), J2.MP (MountPin), J6.3, J6.5, J8.7 (GND), J8.MP (MountPin), R13.1, R21.1, R23.2, SW2.1, SW2.3, SW2.5 (SHIELD), U3.4 (GND), U4.2 (GND), U5.2 (GND), U5.5 (DIR), U6.2 (V-), U7.2 (GND); also elsewhere on the board
IF_VREF: C28.1, C29.1, C31.2, C36.2, C38.2, JP2.1 (A), JP2.2 (C), R12.2, R14.2, R17.1, R20.2, R22.1, U3.8 (VCCB), U4.6 (VCCB), U5.6 (VCCB), U7.6 (VCCB); also elsewhere on the board
unnamed: R17.2, R18.2, U6.1
unnamed: R9.2, U3.7 (1B)
unnamed: R10.2, U3.6 (2B)
unnamed: R11.1, R12.1, U4.4 (B)
unnamed: R15.1, U6.3 (+)
unnamed: R18.1, U6.4 (-)
unnamed: C32.1, C33.1, L5.2, U6.5 (V+)
unnamed: R19.1, R20.1, U7.4 (B)
RX_FROM_LPC: J1.3 (Console_RX), J2.3 (Console_RX), J8.3 (Console_RX); also elsewhere on the board
TX_TO_LPC: J1.2 (Console_TX), J2.2 (Console_TX), J8.2 (Console_TX); also elsewhere on the board

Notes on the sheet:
NOTE: connection 1-2 in layout!
Tracking of reference voltage
Target Cortex Debug (SWD/JTAG)
Target Reset
https://nxp.gitbook.io/hovergames/rddrone-fmuk66/connectors/debug-interface-dcd-lz
FTDI Yellow: -> to PC FTDI Orange: <- from PC
Debug Console: TX/RX is from PX4 point of view Holybro Pixhawk 6X RT: 115200 baud
0.8-0.45mA leakage
Pin 2: PX4 Tx to LPC55S69 Pin 3: PX4 Rx from LPC55S69
Debug Interface
Default: 1-2 closed, 2-3 open

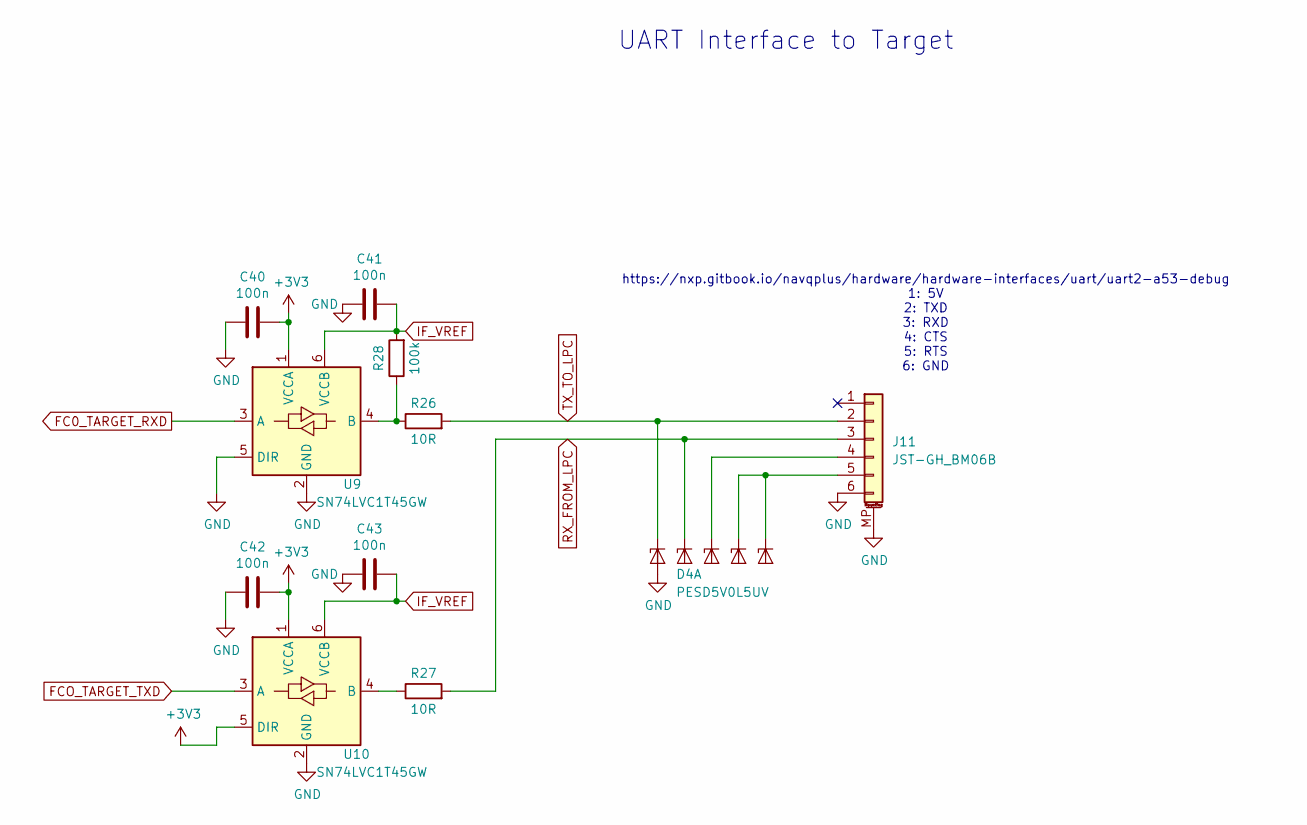
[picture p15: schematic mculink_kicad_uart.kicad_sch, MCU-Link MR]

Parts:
C40, C41, C42, C43: 100n; C_0603_1608Metric
D4: PESD5V0L5UV; SOT-666
J11: JST-GH_BM06B; JST_GH_BM06B-GHS-TBT_1x06-1MP_P1.25mm_Vertical
R26, R27: 10R; R_0603_1608Metric
R28: 100k; R_0603_1608Metric
U9, U10: SN74LVC1T45GW; SOT-363_SC-70-6

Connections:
+3V3: C40.2, C42.2, U9.1 (VCCA), U10.1 (VCCA), U10.5 (DIR); also elsewhere on the board
FC0_TARGET_RXD: U9.3 (A); also elsewhere on the board
FCO_TARGET_TXD: U10.3 (A); also elsewhere on the board
GND: C40.1, C41.1, C42.1, C43.1, D4.2 (A), J11.6, J11.MP (MountPin), U9.2 (GND), U9.5 (DIR), U10.2 (GND); also elsewhere on the board
IF_VREF: C41.2, C43.2, R28.2, U9.6 (VCCB), U10.6 (VCCB); also elsewhere on the board
unnamed: D4.4 (K3), J11.4
unnamed: D4.5 (K4), D4.6 (K5), J11.5
unnamed: R26.1, R28.1, U9.4 (B)
unnamed: R27.1, U10.4 (B)
RX_FROM_LPC: D4.3 (K2), J11.3, R27.2; also elsewhere on the board
TX_TO_LPC: D4.1 (K1), J11.2, R26.2; also elsewhere on the board

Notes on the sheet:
UART Interface to Target
https://nxp.gitbook.io/navqplus/hardware/hardware-interfaces/uart/uart2-a53-debug 1: 5V 2: TXD 3: RXD 4: CTS 5: RTS 6: GND

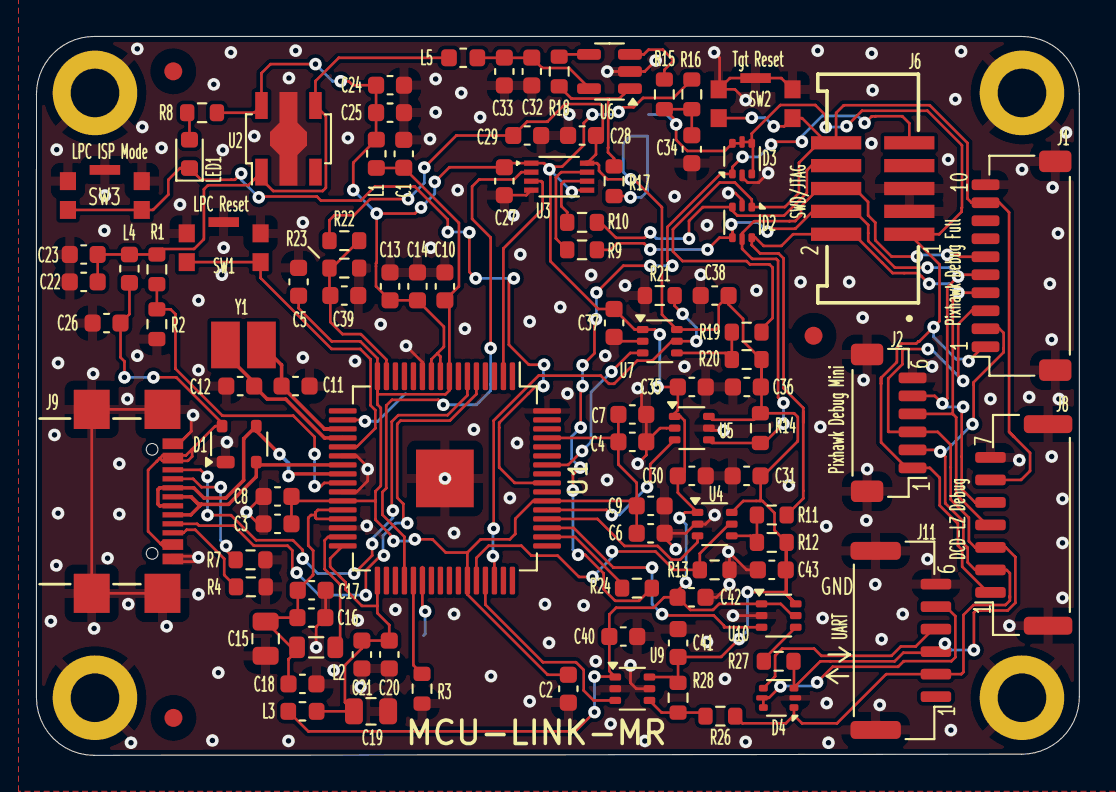
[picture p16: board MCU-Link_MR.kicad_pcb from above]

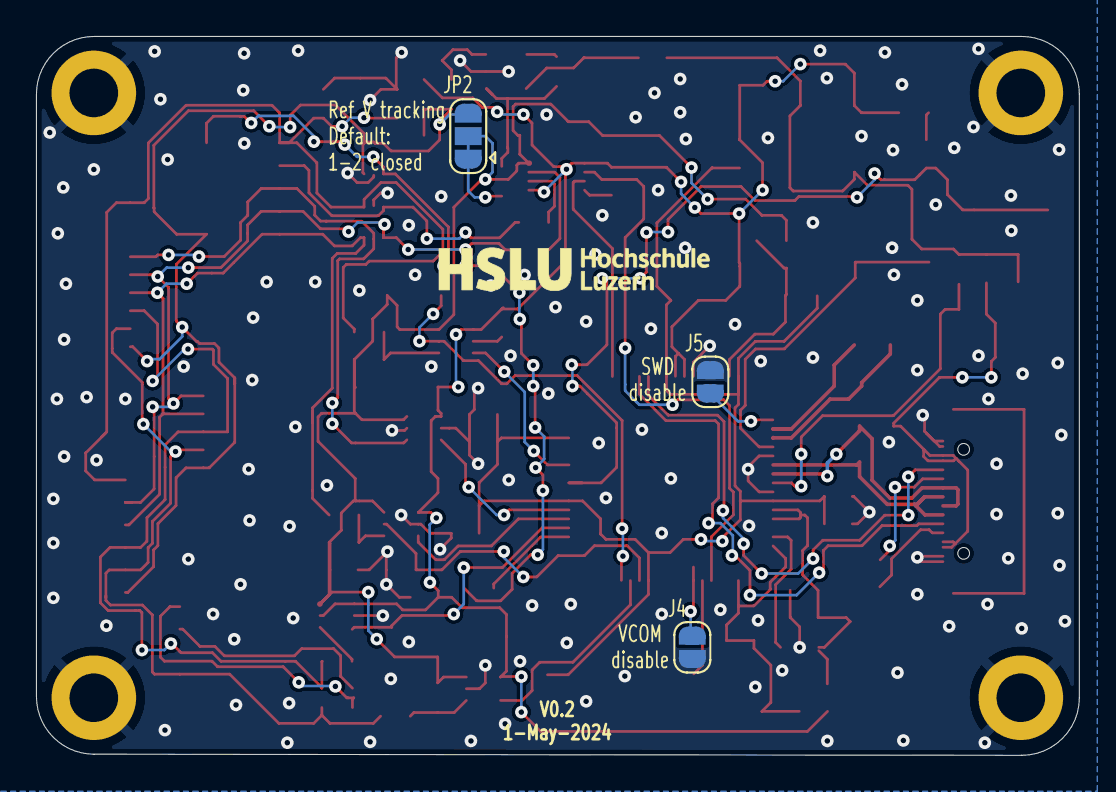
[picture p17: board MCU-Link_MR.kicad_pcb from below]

Board: 2 copper layers, 57.9 x 39.9 mm, 108 parts (4 on the bottom side), 56 nets.

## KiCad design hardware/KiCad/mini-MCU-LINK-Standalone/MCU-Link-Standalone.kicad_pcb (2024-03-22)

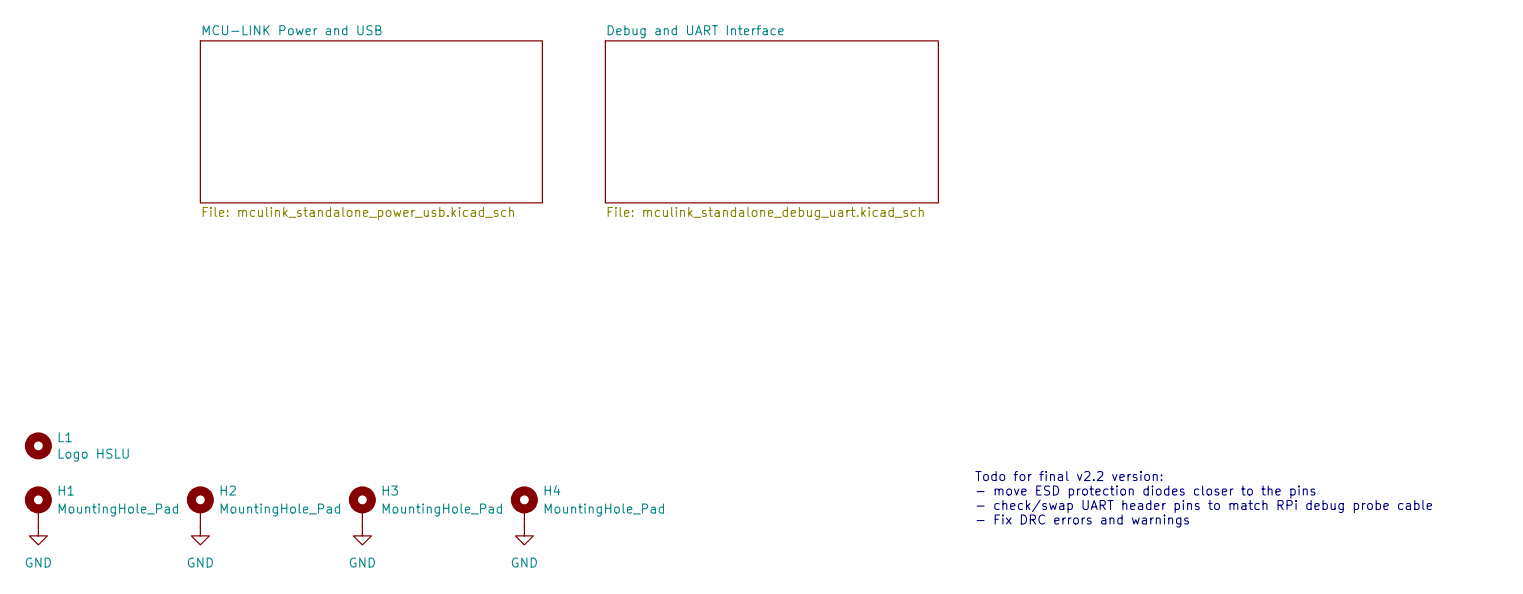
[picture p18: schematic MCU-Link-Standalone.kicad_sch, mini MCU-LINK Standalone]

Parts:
H1, H2, H3, H4: MountingHole_Pad; MountingHole_2.2mm_M2_ISO7380_Pad_TopBottom_with_holes
L1: Logo HSLU; Hochschule_Luzern_New

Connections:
GND: H1.1, H2.1, H3.1, H4.1; also elsewhere on the board

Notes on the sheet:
Todo for final v2.2 version: - move ESD protection diodes closer to the pins - check/swap UART header pins to match RPi debug probe cable - Fix DRC errors and warnings

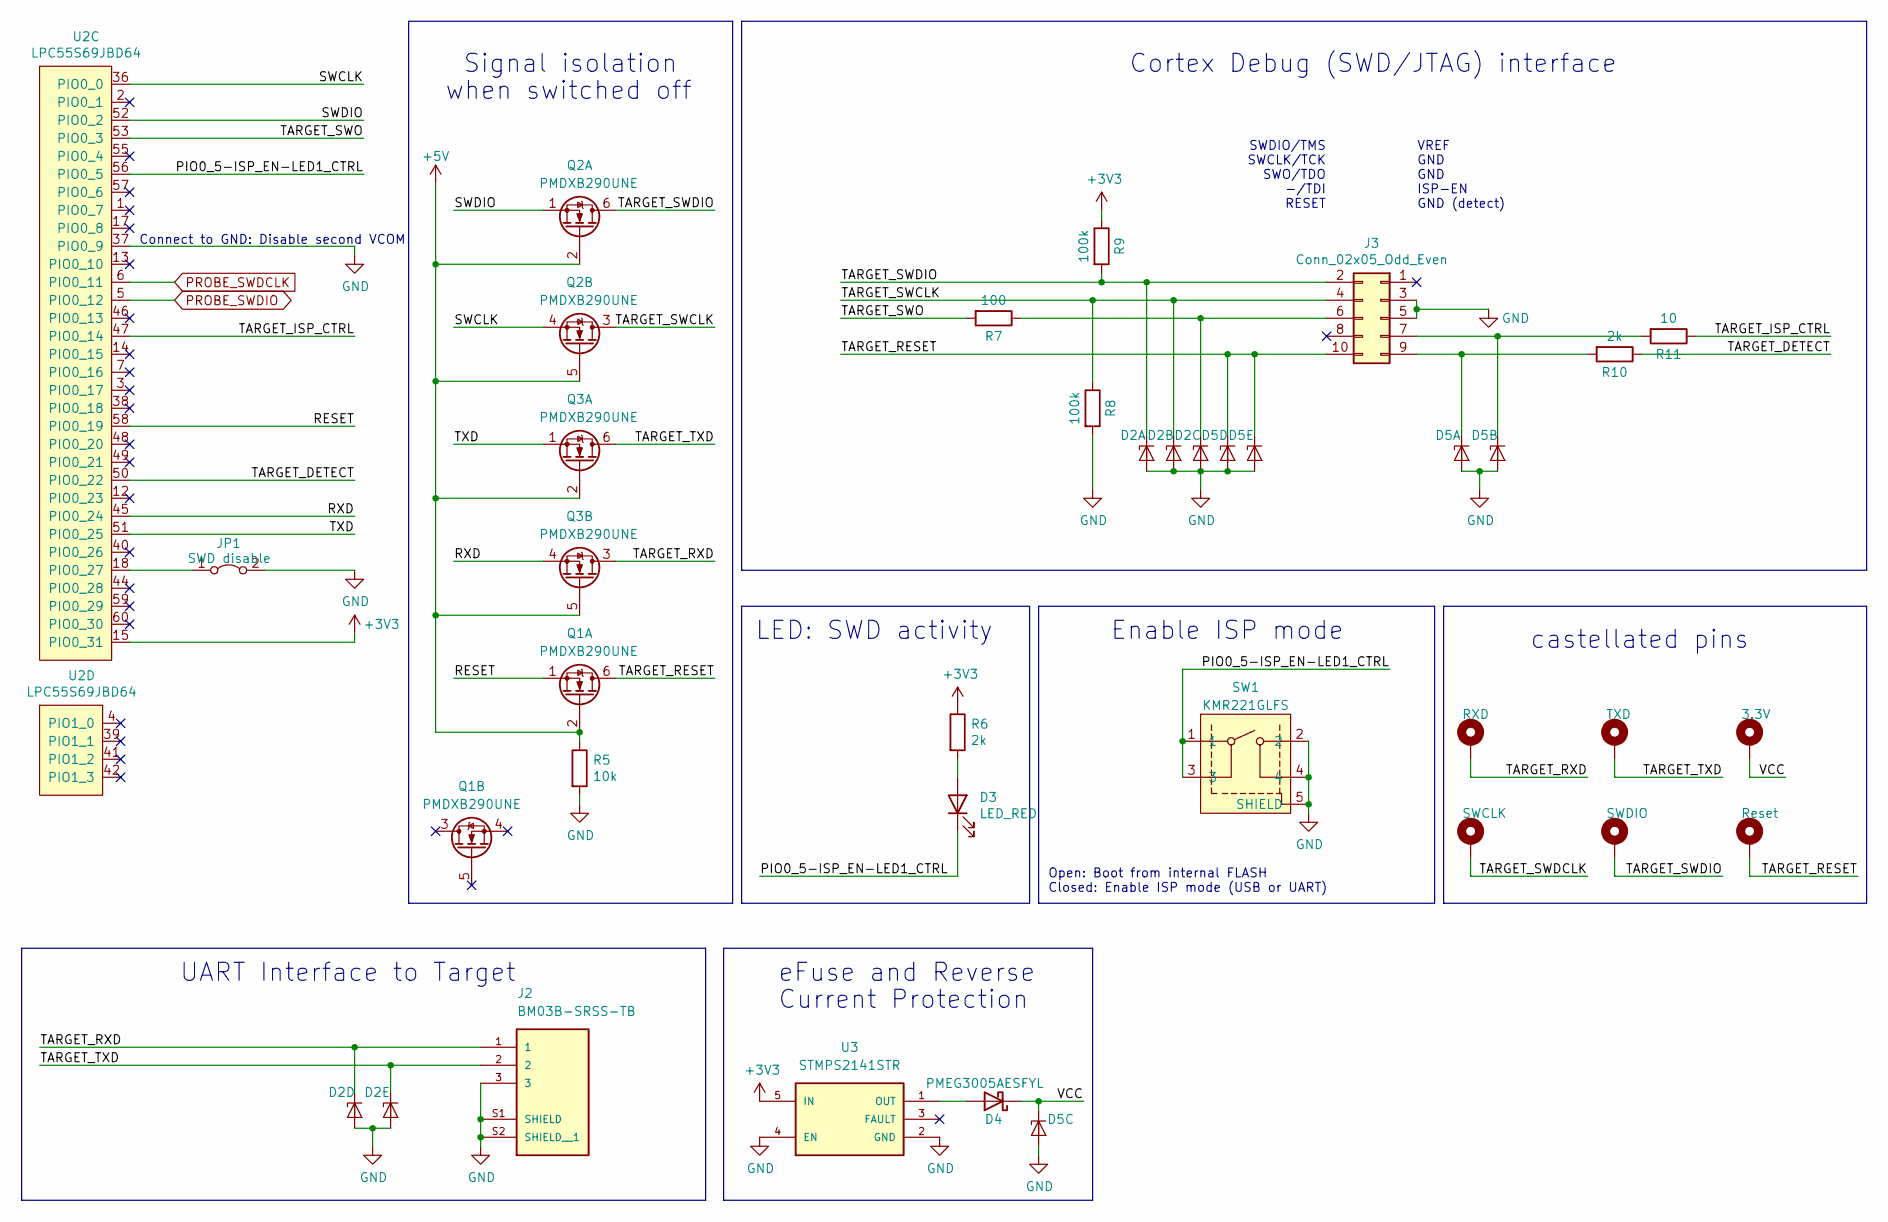
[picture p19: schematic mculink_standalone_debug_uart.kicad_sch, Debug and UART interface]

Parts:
D2, D5: PESD5V0L5UV; SOT-666
D3: LED_RED; LED_0402_1005Metric
D4: PMEG3005AESFYL; Nexperia_DSN0603-2_0.6x0.3mm_P0.4mm
H5: RXD; castellated pin
H6: SWCLK; castellated pin
H7: TXD; castellated pin
H8: SWDIO; castellated pin
H9: 3.3V; castellated pin
H10: Reset; castellated pin
J2: BM03B-SRSS-TB; JST_BM03B-SRSS-TB_LF__SN_; PARTREV N/A
J3: Conn_02x05_Odd_Even; SWD_Pin_Header_Straight_2x05_Pitch1.27mm_SMD
JP1: SWD disable; SolderJumper-2_P1.3mm_Open_RoundedPad1.0x1.5mm
Q1, Q2, Q3: PMDXB290UNE; SOT1216
R5: 10k; R_0402_1005Metric
R6, R10: 2k; R_0402_1005Metric
R7: 100; R_0402_1005Metric
R8, R9: 100k; R_0402_1005Metric
R11: 10; R_0402_1005Metric
SW1: KMR221GLFS; SW_C_K_KMR2
U2: LPC55S69JBD64; LQFP-64-1EP_10x10mm_P0.5mm_EP5x5mm
U3: STMPS2141STR; SOT95P280X145-5N

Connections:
+3V3: R6.1, R9.1, U2.15 (PIO0_31), U3.5 (IN); also elsewhere on the board
+5V: Q1.2 (G), Q2.2 (G), Q2.5 (G), Q3.2 (G), Q3.5 (G), R5.1; also elsewhere on the board
/Debug and UART Interface/PIO0_5-ISP_EN-LED1_CTRL: D3.1 (K), SW1.1, SW1.3, U2.56 (PIO0_5)
/Debug and UART Interface/RESET: Q1.1 (S), U2.58 (PIO0_19)
/Debug and UART Interface/RXD: Q3.4 (S), U2.45 (PIO0_24)
/Debug and UART Interface/SWCLK: Q2.4 (S), U2.36 (PIO0_0)
/Debug and UART Interface/SWDIO: Q2.1 (S), U2.52 (PIO0_2)
/Debug and UART Interface/TARGET_DETECT: R10.1, U2.50 (PIO0_22)
/Debug and UART Interface/TARGET_ISP_CTRL: R11.1, U2.47 (PIO0_14)
/Debug and UART Interface/TARGET_RESET: D5.5 (K4), D5.6 (K5), H10.1, J3.10, Q1.6 (D)
/Debug and UART Interface/TARGET_RXD: D2.5 (K4), H5.1, J2.1, Q3.3 (D)
/Debug and UART Interface/TARGET_SWCLK: D2.3 (K2), J3.4, Q2.3 (D), R8.1
/Debug and UART Interface/TARGET_SWDCLK: H6.1
/Debug and UART Interface/TARGET_SWDIO: D2.1 (K1), H8.1, J3.2, Q2.6 (D), R9.2
/Debug and UART Interface/TARGET_SWO: R7.2, U2.53 (PIO0_3)
/Debug and UART Interface/TARGET_TXD: D2.6 (K5), H7.1, J2.2, Q3.6 (D)
/Debug and UART Interface/TXD: Q3.1 (S), U2.51 (PIO0_25)
/Debug and UART Interface/VCC: D4.1 (K), D5.4 (K3), H9.1
GND: D2.2 (A), D5.2 (A), J2.3, J2.S1 (SHIELD), J2.S2 (SHIELD__1), J3.3, J3.5, JP1.2 (B), R5.2, R8.2, SW1.2, SW1.4, SW1.5 (SHIELD), U2.37 (PIO0_9), U3.2 (GND), U3.4 (EN); also elsewhere on the board
unnamed: D2.4 (K3), J3.6, R7.1
unnamed: D3.2 (A), R6.2
unnamed: D4.2 (A), U3.1 (OUT)
unnamed: D5.1 (K1), J3.9, R10.2
unnamed: D5.3 (K2), J3.7, R11.2
unnamed: JP1.1 (A), U2.18 (PIO0_27)
PROBE_SWDCLK: U2.6 (PIO0_11); also elsewhere on the board
PROBE_SWDIO: U2.5 (PIO0_12); also elsewhere on the board

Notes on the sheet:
Connect to GND: Disable second VCOM
when switched off
VREF GND GND ISP-EN GND (detect)
UART Interface to Target
SWDIO/TMS SWCLK/TCK SWO/TDO -/TDI RESET
Cortex Debug (SWD/JTAG) interface
LED: SWD activity
eFuse and Reverse
Signal isolation
castellated pins
Enable ISP mode
Current Protection
Open: Boot from internal FLASH Closed: Enable ISP mode (USB or UART)

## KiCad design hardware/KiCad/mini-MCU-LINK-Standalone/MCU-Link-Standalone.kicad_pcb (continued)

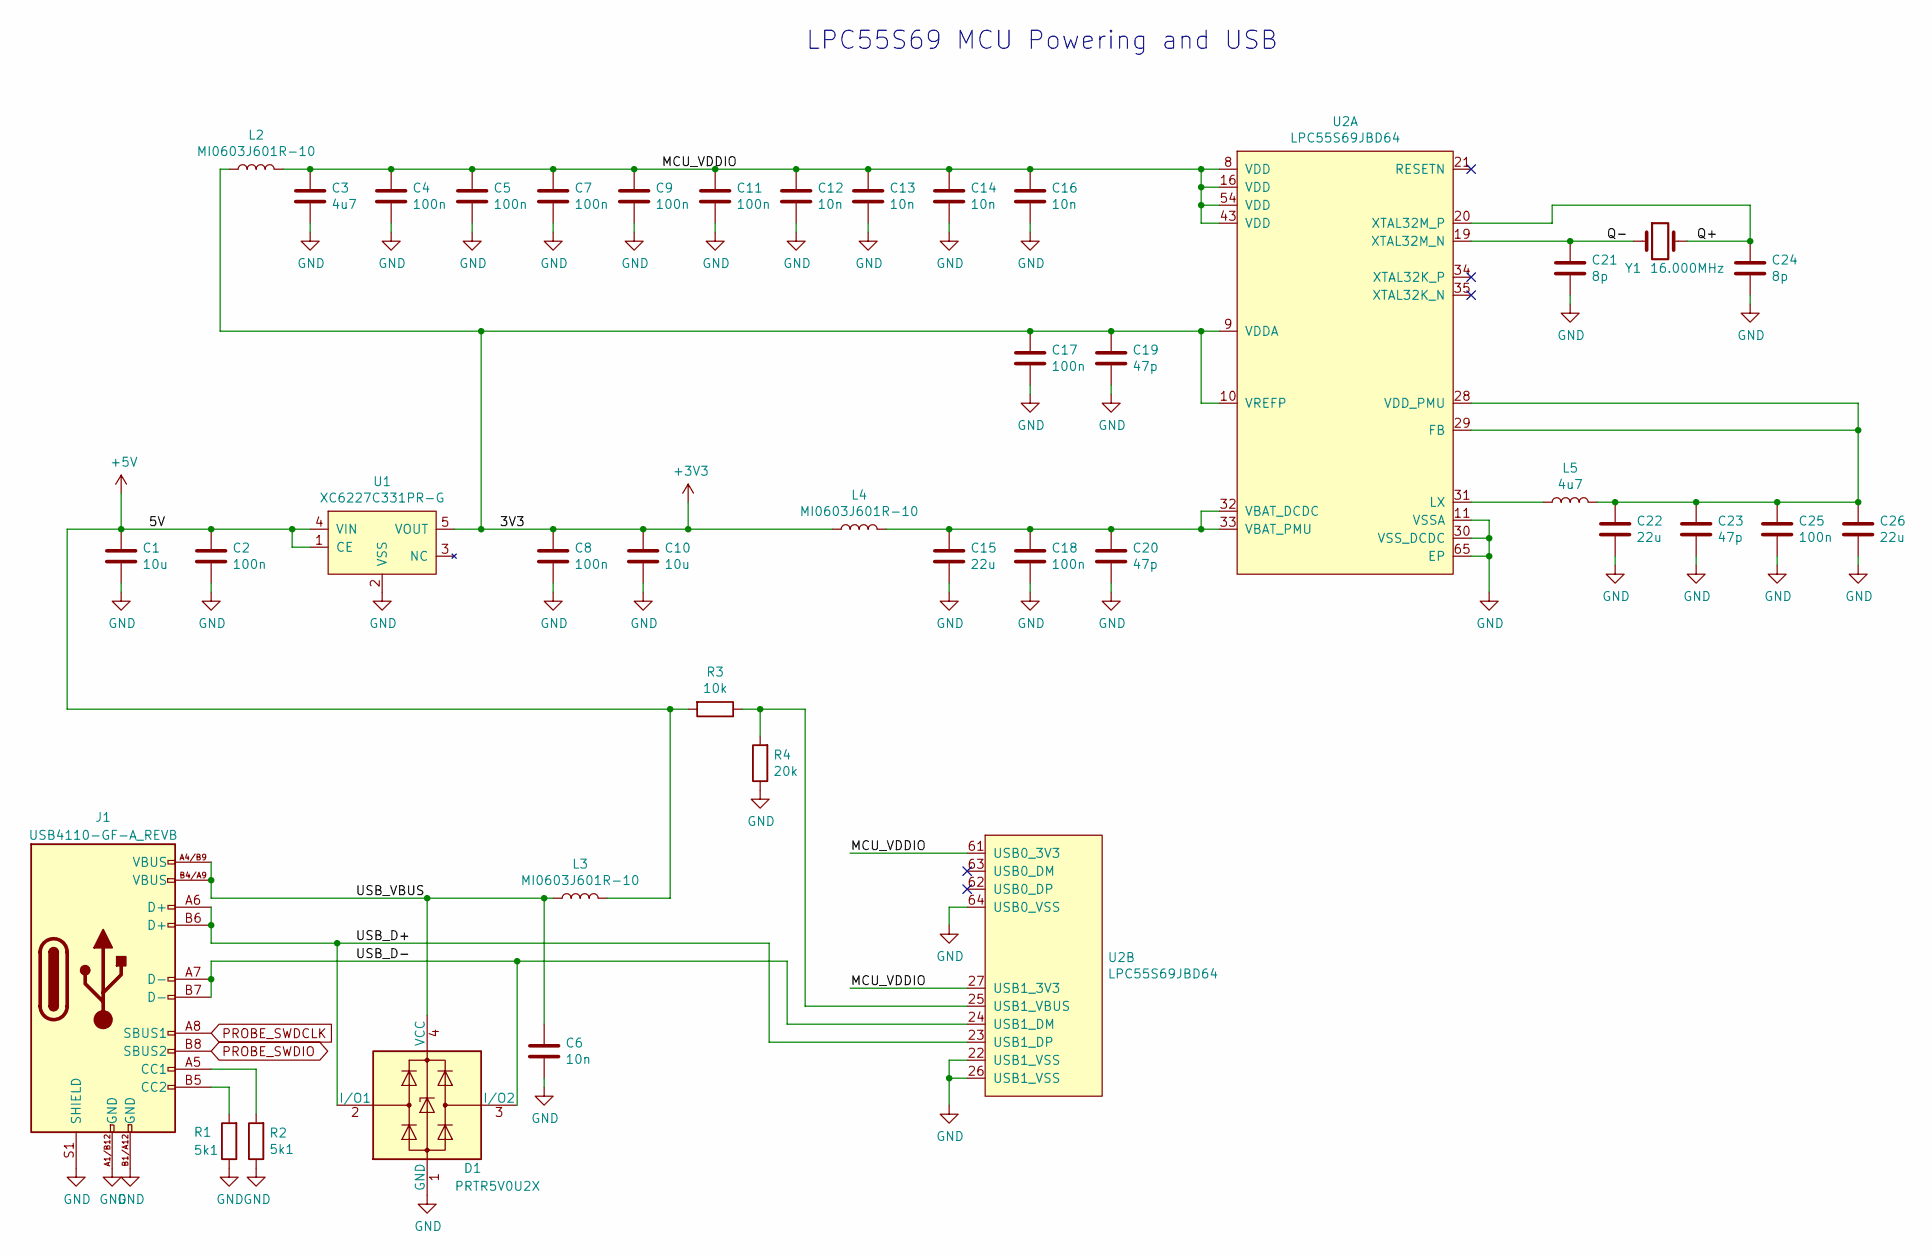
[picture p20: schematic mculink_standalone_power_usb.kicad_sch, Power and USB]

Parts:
C1, C10: 10u; C_0402_1005Metric
C2, C4, C5, C7, C8, C9, C11, C17, C18, C25: 100n; C_0402_1005Metric
C3: 4u7; C_0402_1005Metric
C6, C12, C13, C14, C16: 10n; C_0402_1005Metric
C15, C22, C26: 22u; C_0402_1005Metric
C19, C20, C23: 47p; C_0402_1005Metric
C21, C24: 8p; C_0402_1005Metric
D1: PRTR5V0U2X; SOT143B
J1: USB4110-GF-A_REVB; USB_C_Receptacle_GCT_USB4110-GF-A; PARTREV B
L2, L3, L4: MI0603J601R-10; L_0603_1608Metric
L5: 4u7; L_0603_1608Metric
R1, R2: 5k1; R_0402_1005Metric
R3: 10k; R_0402_1005Metric
R4: 20k; R_0402_1005Metric
U1: XC6227C331PR-G; SOT-89-5
U2: LPC55S69JBD64; LQFP-64-1EP_10x10mm_P0.5mm_EP5x5mm
Y1: 16.000MHz; CX3225GA16000D0PTVCC

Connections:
+3V3: C8.1, C10.1, C17.1, C19.1, L2.1, L4.1, U1.5 (VOUT), U2.9 (VDDA), U2.10 (VREFP); also elsewhere on the board
+5V: C1.1, C2.1, L3.2, R3.2, U1.1 (CE), U1.4 (VIN); also elsewhere on the board
/MCU-LINK Power and USB/MCU_VDDIO: C3.1, C4.1, C5.1, C7.1, C9.1, C11.1, C12.1, C13.1, C14.1, C16.1, L2.2, U2.8 (VDD), U2.16 (VDD), U2.27 (USB1_3V3), U2.43 (VDD), U2.54 (VDD), U2.61 (USB0_3V3)
/MCU-LINK Power and USB/Q+: C24.1, U2.20 (XTAL32M_P), Y1.2
/MCU-LINK Power and USB/Q-: C21.1, U2.19 (XTAL32M_N), Y1.1
/MCU-LINK Power and USB/USB_D+: D1.2 (I/O1), J1.A6 (D+), J1.B6 (D+), U2.23 (USB1_DP)
/MCU-LINK Power and USB/USB_D-: D1.3 (I/O2), J1.A7 (D-), J1.B7 (D-), U2.24 (USB1_DM)
/MCU-LINK Power and USB/USB_VBUS: C6.1, D1.4 (VCC), J1.A4/B9 (VBUS), J1.B4/A9 (VBUS), L3.1
GND: C1.2, C2.2, C3.2, C4.2, C5.2, C6.2, C7.2, C8.2, C9.2, C10.2, C11.2, C12.2, C13.2, C14.2, C15.2, C16.2, C17.2, C18.2, C19.2, C20.2, C21.2, C22.2, C23.2, C24.2, C25.2, C26.2, D1.1 (GND), J1.A1/B12 (GND), J1.B1/A12 (GND), J1.S1 (SHIELD), R1.1, R2.1, R4.1, U1.2 (VSS), U2.11 (VSSA), U2.22 (USB1_VSS), U2.26 (USB1_VSS), U2.30 (VSS_DCDC), U2.64 (USB0_VSS), U2.65 (EP); also elsewhere on the board
unnamed: J1.A5 (CC1), R2.2
unnamed: J1.B5 (CC2), R1.2
unnamed: C22.1, C23.1, C25.1, C26.1, L5.2, U2.28 (VDD_PMU), U2.29 (FB)
unnamed: L5.1, U2.31 (LX)
unnamed: C15.1, C18.1, C20.1, L4.2, U2.32 (VBAT_DCDC), U2.33 (VBAT_PMU)
unnamed: R3.1, R4.2, U2.25 (USB1_VBUS)
PROBE_SWDCLK: J1.A8 (SBUS1); also elsewhere on the board
PROBE_SWDIO: J1.B8 (SBUS2); also elsewhere on the board

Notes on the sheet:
LPC55S69 MCU Powering and USB

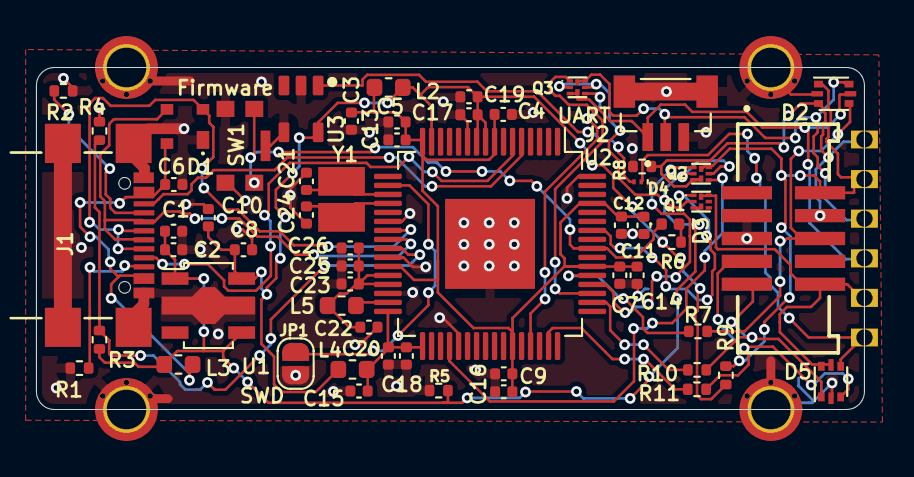
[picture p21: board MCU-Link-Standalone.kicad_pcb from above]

Board: 2 copper layers, 46.0 x 19.0 mm, 69 parts (1 on the bottom side), 38 nets.

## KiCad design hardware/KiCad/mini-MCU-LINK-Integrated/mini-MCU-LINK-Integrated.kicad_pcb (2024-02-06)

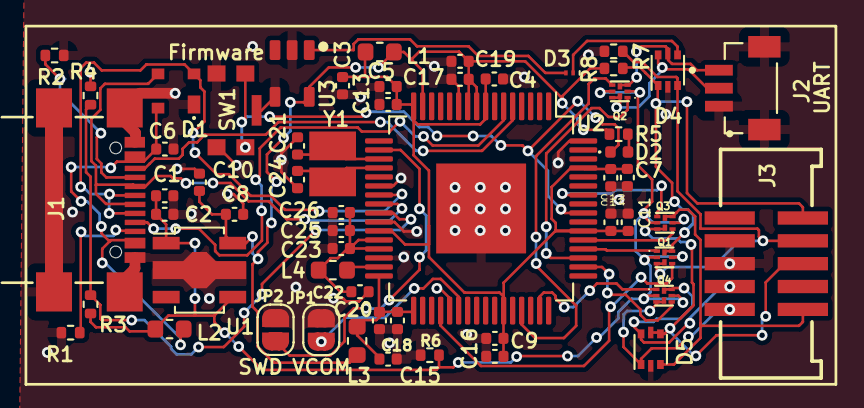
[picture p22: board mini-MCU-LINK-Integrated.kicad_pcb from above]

Board: 2 copper layers, 57 parts (0 on the bottom side), 39 nets.

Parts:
C1, C10: 10u; C_0402_1005Metric
C2, C4, C5, C7, C8, C9, C11, C17, C18, C25: 100n; C_0402_1005Metric
C3: 4u7; C_0402_1005Metric
C6, C12, C13, C14, C16: 10n; C_0402_1005Metric
C15, C22, C26: 22u; C_0402_1005Metric
C19, C20, C23: 47p; C_0402_1005Metric
C21, C24: 8p; C_0402_1005Metric
D1: PRTR5V0U2X; SOT143B
D2: LED_RED; LED_0402_1005Metric
D3: PMEG3005AESFYL; Nexperia_DSN0603-2_0.6x0.3mm_P0.4mm
D4, D5: PESD5V0L5UV; SOT-666
J1: USB4110-GF-A_REVB; USB_C_Receptacle_GCT_USB4110-GF-A
J2: BM03B-SRSS-TB; JST_BM03B-SRSS-TB_LF__SN_
J3: Conn_02x05_Odd_Even; SWD_Pin_Header_Straight_2x05_Pitch1.27mm_SMD
JP1: VCOM disable; SolderJumper-2_P1.3mm_Open_RoundedPad1.0x1.5mm
JP2: SWD disable; SolderJumper-2_P1.3mm_Open_RoundedPad1.0x1.5mm
L1, L2, L3: MI0603J601R-10; L_0603_1608Metric
L4: 4u7; L_0603_1608Metric
Q1, Q2, Q3, Q4: PMDXB290UNE; SOT1216
R1, R2: 5k1; R_0402_1005Metric
R3, R6: 10k; R_0402_1005Metric
R4: 20k; R_0402_1005Metric
R5: 2k; R_0402_1005Metric
R7, R8: 100k; R_0402_1005Metric
SW1: KMR221GLFS; SW_C_K_KMR2
U1: XC6227C331PR-G; SOT-89-5
U2: LPC55S69JBD64; LQFP-64-1EP_10x10mm_P0.5mm_EP5x5mm
U3: STMPS2141STR; SOT95P280X145-5N
Y1: 16.000MHz; CX3225GA16000D0PTVCC

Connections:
+3V3: C8.1, C10.1, C17.1, C19.1, L1.1, L3.1, R5.1, R8.1, U1.5 (VOUT), U2.9 (VDDA), U2.10 (VREFP), U2.15 (PIO0_31), U3.5 (IN)
+5V: C1.1, C2.1, L2.2, Q1.2 (G), Q1.5 (G), Q2.2 (G), Q2.5 (G), Q3.2 (G), Q3.5 (G), Q4.2 (G), Q4.5 (G), R3.2, R6.1, U1.1 (CE), U1.4 (VIN)
/mini MCU-LINK Debug and UART interface/DETECT: Q4.4 (S), U2.50 (PIO0_22)
/mini MCU-LINK Debug and UART interface/ISP_CTRL: Q4.1 (S), U2.47 (PIO0_14)
/mini MCU-LINK Debug and UART interface/PIO0_5-ISP_EN-LED1_CTRL: D2.1 (K), SW1.1, SW1.3, U2.56 (PIO0_5)
/mini MCU-LINK Debug and UART interface/RESET: Q3.1 (S), U2.58 (PIO0_19)
/mini MCU-LINK Debug and UART interface/RXD: Q2.4 (S), U2.45 (PIO0_24)
/mini MCU-LINK Debug and UART interface/SWCLK: Q1.4 (S), U2.36 (PIO0_0)
/mini MCU-LINK Debug and UART interface/SWDIO: Q1.1 (S), U2.52 (PIO0_2)
/mini MCU-LINK Debug and UART interface/SWD_DISABLE: JP2.1 (A), U2.18 (PIO0_27)
/mini MCU-LINK Debug and UART interface/SWO: Q3.4 (S), U2.53 (PIO0_3)
/mini MCU-LINK Debug and UART interface/TARGET_DETECT: D5.1 (K1), J3.9, Q4.3 (D)
/mini MCU-LINK Debug and UART interface/TARGET_ISP_CTRL: D5.6 (K5), J3.7, Q4.6 (D)
/mini MCU-LINK Debug and UART interface/TARGET_RESET: D5.3 (K2), J3.10, Q3.6 (D)
/mini MCU-LINK Debug and UART interface/TARGET_RXD: D4.5 (K4), J2.1, Q2.3 (D)
/mini MCU-LINK Debug and UART interface/TARGET_SWCLK: D4.3 (K2), J3.4, Q1.3 (D), R7.1
/mini MCU-LINK Debug and UART interface/TARGET_SWDIO: D4.1 (K1), J3.2, Q1.6 (D), R8.2
/mini MCU-LINK Debug and UART interface/TARGET_SWO: D5.4 (K3), D5.5 (K4), J3.6, Q3.3 (D)
/mini MCU-LINK Debug and UART interface/TARGET_TXD: D4.6 (K5), J2.2, Q2.6 (D)
/mini MCU-LINK Debug and UART interface/TXD: Q2.1 (S), U2.51 (PIO0_25)
/mini MCU-LINK Debug and UART interface/VCC: D3.1 (K), D4.4 (K3)
/mini MCU-LINK Debug and UART interface/VCOM_DISABLE: JP1.1 (A), U2.38 (PIO0_18)
/mini MCU-LINK Power and USB/MCU_VDDIO: C3.1, C4.1, C5.1, C7.1, C9.1, C11.1, C12.1, C13.1, C14.1, C16.1, L1.2, U2.8 (VDD), U2.16 (VDD), U2.27 (USB1_3V3), U2.43 (VDD), U2.54 (VDD), U2.61 (USB0_3V3)
/mini MCU-LINK Power and USB/Q+: C24.1, U2.20 (XTAL32M_P), Y1.2
/mini MCU-LINK Power and USB/Q-: C21.1, U2.19 (XTAL32M_N), Y1.1
/mini MCU-LINK Power and USB/USB_D+: D1.2 (I/O1), J1.A6 (D+), J1.B6 (D+), U2.23 (USB1_DP)
/mini MCU-LINK Power and USB/USB_D-: D1.3 (I/O2), J1.A7 (D-), J1.B7 (D-), U2.24 (USB1_DM)
/mini MCU-LINK Power and USB/USB_VBUS: C6.1, D1.4 (VCC), J1.A4/B9 (VBUS), J1.B4/A9 (VBUS), L2.1
GND: C1.2, C2.2, C3.2, C4.2, C5.2, C6.2, C7.2, C8.2, C9.2, C10.2, C11.2, C12.2, C13.2, C14.2, C15.2, C16.2, C17.2, C18.2, C19.2, C20.2, C21.2, C22.2, C23.2, C24.2, C25.2, C26.2, D1.1 (GND), D4.2 (A), D5.2 (A), J1.A1/B12 (GND), J1.B1/A12 (GND), J1.S1 (SHIELD), J2.3, J2.S1 (SHIELD), J2.S2 (SHIELD__1), J3.3, J3.5, JP1.2 (B), JP2.2 (B), R1.1, R2.1, R4.1, R6.2, R7.2, SW1.2, SW1.4, SW1.5 (SHIELD), U1.2 (VSS), U2.11 (VSSA), U2.22 (USB1_VSS), U2.26 (USB1_VSS), U2.30 (VSS_DCDC), U2.37 (PIO0_9), U2.64 (USB0_VSS), U2.65 (EP), U3.2 (GND), U3.4 (EN)
unnamed: D2.2 (A), R5.2
unnamed: D3.2 (A), U3.1 (OUT)
unnamed: J1.A5 (CC1), R2.2
unnamed: J1.B5 (CC2), R1.2
unnamed: C22.1, C23.1, C25.1, C26.1, L4.2, U2.28 (VDD_PMU), U2.29 (FB)
unnamed: L4.1, U2.31 (LX)
unnamed: C15.1, C18.1, C20.1, L3.2, U2.32 (VBAT_DCDC), U2.33 (VBAT_PMU)
unnamed: R3.1, R4.2, U2.25 (USB1_VBUS)
PROBE_SWDCLK: J1.A8 (SBUS1), U2.6 (PIO0_11)
PROBE_SWDIO: J1.B8 (SBUS2), U2.5 (PIO0_12)

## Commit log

2024-02-01 initial version, from PAIND of Dario Scheuber
    [BM03B-SRSS-TB_LF__SN_.step, KMR221GLFS.step, LQFP-64-1EP_10x10mm_P0.5mm_EP6.5x6.5mm.step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]
2024-02-05 fixed some DRC errors and warnings
    [MCU-Link-Standalone.kicad_pcb, mculink_standalone_debug_uart.kicad_sch]
2024-02-06 added notes, updated 3D model
    [MCU-Link-Standalone.kicad_sch, mculink_standalone_debug_uart.kicad_sch, mini-MCU-LINK-Integrated.kicad_pcb]
2024-03-11 added initial drone version (work in progress)
    [BM03B-SRSS-TB_LF__SN_.step, KMR221GLFS.step, LQFP-64-1EP_10x10mm_P0.5mm_EP6.5x6.5mm.step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]
2024-03-12 updated schematic part
    [mculink_standalone_debug_uart.kicad_sch, mculink_standalone_power_usb.kicad_sch]
2024-03-12 cleanup and ERC fixes
    [MCU-Link-Drone.kicad_sch, mculink_standalone_debug_uart.kicad_sch, mculink_standalone_power_usb.kicad_sch]
2024-03-12 made it warning free with KiCAD 8
    [mculink_standalone_debug_uart.kicad_sch, mculink_standalone_power_usb.kicad_sch]
2024-03-22 added new project for Drone
    [BM03B-SRSS-TB_LF__SN_.step, KMR221GLFS.step, LQFP-64-1EP_10x10mm_P0.5mm_EP6.5x6.5mm.step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]
2024-03-22 updated with drone project files
    [BOM.xlsx, MCU-Link-Standalone.kicad_pcb, MCU-Link-Standalone.kicad_sch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]
2024-03-22 updated BOM
    [BOM.xlsx]
2024-03-22 worked on layout
    [mculink_kicad.kicad_pcb, mculink_kicad.kicad_sch, mculink_kicad_debug.kicad_sch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]
2024-03-22 fixed warnings
    [mculink_drone_kicad.kicad_pcb, mculink_drone_kicad.kicad_sch, mculink_kicad_debug.kicad_sch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]
2024-03-24 added 3D models
    [mculink_drone_kicad.kicad_pcb, mculink_drone_kicad.kicad_sch, mculink_kicad_debug.kicad_sch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]
2024-03-24 improved layout
    [mculink_drone_kicad.kicad_pcb, mculink_kicad_ioports.kicad_sch, mculink_kicad_power_usb.kicad_sch]
2024-03-25 optimized layout
    [mculink_drone_kicad.kicad_pcb, mculink_kicad_debug.kicad_sch, mculink_kicad_ioports.kicad_sch]
2024-03-25 optimized traces
    [mculink_drone_kicad.kicad_pcb]
2024-03-26 added JST-GH for UART
    [mculink_drone_kicad.kicad_pcb, mculink_kicad_uart.kicad_sch]
2024-03-27 production files for V0.1
    [mculink_drone_kicad.kicad_pcb, mculink_kicad_debug.kicad_sch]
2024-03-27 fixed silkscreen
    [mculink_drone_kicad.kicad_pcb]
2024-04-12 updated schematics
    [mculink_drone_kicad.kicad_pcb, mculink_drone_kicad.kicad_sch, mculink_kicad_ioports.kicad_sch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]
2024-04-23 updated parts and minor tweaks
    [mculink_drone_kicad.kicad_sch, mculink_kicad_debug.kicad_sch, mculink_kicad_ioports.kicad_sch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]
2024-04-29 moved files
    [BOM.xlsx, MCU-Link_MR.kicad_pcb, MCU-Link_MR.kicad_sch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]
2024-04-29 consolidated notes
    [MCU-Link_MR.kicad_pcb, MCU-Link_MR.kicad_sch]
2024-04-29 added enclosure
2024-05-01 sent v0.2 to PCB production
    [MCU-Link_MR.kicad_pcb, MCU-Link_MR.kicad_sch, mculink_kicad_ioports.kicad_sch]
